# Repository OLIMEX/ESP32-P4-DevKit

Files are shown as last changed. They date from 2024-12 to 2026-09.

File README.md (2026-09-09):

# ESP32-P4-DevKit
Development board for ESP32-P4 Dual core RISCV processor from Espressif

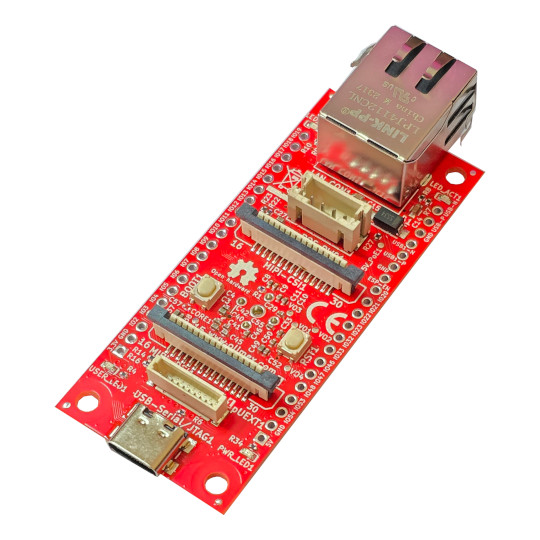
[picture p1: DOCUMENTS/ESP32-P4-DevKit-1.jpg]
ESP32-P4-DevKit-1


https://www.olimex.com/Products/IoT/ESP32-P4/ESP32-P4-DevKit/open-source-hardware

## MIPI-LCD2.8 demos

The ESP-IDF MIPI display demos under `SOFTWARE/Demo_Examples` support both Olimex MIPI-LCD2.8 revisions. They default to WLK2802MIPI-15P-V2. See the per-demo readmes for build instructions and [CHANGELOG.md](CHANGELOG.md) for this revision's configuration changes.

## Licensee
* Hardware is released under CERN Open Hardware Licence Version 2 - Strongly Reciprocal
* Software is released under GPL V3 Licensee
* Documentation is released under CC BY-SA 4.0

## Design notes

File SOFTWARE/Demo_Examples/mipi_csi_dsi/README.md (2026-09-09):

| Supported ESP SoCs | ESP32-P4 |
| --- | ----- |

# MIPI camera and display demo

## Overview

This example streams camera input to the display. It requires a camera, display,
and ESP32-P4 board. It supports both MIPI-LCD2.8 revisions.

## How to use

### ESP-IDF Required

* This demo was made and tested with ESP-IDF `v5.4.1`.
* Please follow the [ESP-IDF Programming Guide](https://docs.espressif.com/projects/esp-idf/en/latest/esp32s3/get-started/index.html) to set up the development environment.

### Hardware Required

* Main board - Olimex [ESP32-P4-DevKit](https://www.olimex.com/Products/IoT/ESP32-P4/ESP32-P4-DevKit/open-source-hardware)
* Display - Olimex [MIPI-LCD2.8-640x480](https://www.olimex.com/Products/RaspberryPi/MIPI-LCD2.8-640x480/)
* Camera - Olimex [CAMERA-OV5647-5MPIX](https://www.olimex.com/Products/Components/Camera/CAMERA-OV5647-5MPIX/)
* USB cable - Type C USB 3.0 cable [USB-CABLE-AM-USB3-C](https://www.olimex.com/Products/Components/Cables/USB/USB-CABLE-AM-USB3-C/)

Connect the camera to MIPI-CSI connector and connect the display to MIPI-DSI connector. Power the main board via the USB type C cable.

### Configurations

V2 (`WLK2802MIPI-15P-V2`) is the default. It uses RGB888 with one MIPI DSI
lane at 500 Mbps and a 16 MHz DPI clock; it has no PCA9536 control expander.

For the original V1 (`WLK2802MIPI-15P`), edit
`main/BOARD_OLIMEX_ESP32_P4_DEVKIT.h` and change:

```c
#define OLIMEX_MIPI_LCD_VERSION (2)
```

to:

```c
#define OLIMEX_MIPI_LCD_VERSION (1)
```

V1 uses the PCA9536 at I2C address `0x41` on GPIO7/GPIO8 for the required
panel reset and backlight sequence. The camera-to-display path remains RGB888.

The demo is otherwise already configured. To review its project settings:

- Run `idf.py menuconfig`

  - See [Configuration Guide](../../../docs/envs/use_with_idf.md#configuration-guide) for more details.

### Build and Flash

Run `idf.py -p <PORT> build flash monitor` to build, flash and monitor the project.

(To exit the serial monitor, type `Ctrl-]`.)

See the [Getting Started Guide](https://docs.espressif.com/projects/esp-idf/en/latest/get-started/index.html) for full steps to configure and use ESP-IDF to build projects.

Generated `build/`, `managed_components/`, and `sdkconfig.old` files are local
build output and should not be committed.

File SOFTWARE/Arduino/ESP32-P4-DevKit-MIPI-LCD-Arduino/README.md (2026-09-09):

# ESP32-P4-DevKit MIPI-LCD2.8 Arduino demo

Arduino/LVGL demo for the Olimex ESP32-P4-DevKit or ESP32-P4-PC and the
MIPI-LCD2.8-640x480 V1 (`WLK2802MIPI-15P`) or V2 (`WLK2802MIPI-15P-V2`)
display. It configures the ST7701 panel for one-lane MIPI DSI, renders an LVGL
status screen, and animates the progress bar continuously. The background
switches between six solid colors every 10 seconds, with text and bar colors
adjusted for contrast. GPIO2 drives the board user LED as a 1 Hz heartbeat.

The display path is RGB888. LVGL renders RGB565 and the local port converts
each updated area to RGB888 before it is copied to the MIPI DSI framebuffer.

## Requirements

- Olimex ESP32-P4-DevKit or ESP32-P4-PC, with the display connected to its
  **MIPI-DSI** connector.
- MIPI-LCD2.8-640x480 V1 or V2 display and its ribbon cable.
- Arduino IDE with **esp32 by Espressif Systems 3.3.8** installed through
  Boards Manager.
- These libraries installed through Library Manager:

| Library | Tested version |
| --- | --- |
| ESP32_Display_Panel | 1.0.4 |
| ESP32_IO_Expander | 1.1.1 |
| esp-lib-utils | 0.3.0 |
| lvgl | 8.4.0 |

Use LVGL 8.4.0. The project does not support LVGL 9.

## Arduino IDE settings

Open `ESP32-P4-DevKit-MIPI-LCD-Arduino.ino`, then select:

| Tools setting | Value |
| --- | --- |
| Board | ESP32P4 Dev Module |
| USB Mode | Hardware CDC and JTAG |
| USB CDC On Boot | **Enabled** |
| Upload Mode | UART0 / Hardware CDC |
| Flash Frequency | 80 MHz |
| Flash Mode | DIO |
| Flash Size | 16 MB |
| **PSRAM** | **Enabled — required** |
| Chip Variant | Before v3.00 for ESP32-P4 revision 1.3 |

`PSRAM: Enabled` is mandatory. The RGB888 480x640 MIPI DSI framebuffer needs
921,600 bytes of PSRAM. If PSRAM is disabled, startup stops with:

```text
lcd.dsi: no memory for frame buffer
Board begin failed
```

Use the appropriate chip variant if the board has later silicon.

## Upload and run

1. Power off before fitting or changing the LCD ribbon.
2. Connect the display to MIPI-DSI, power the board, and select its COM port.
3. Verify, then Upload from Arduino IDE.
4. Apply the Windows DTR/RTS override below before opening Serial Monitor.
5. Open Serial Monitor at **115200 baud**. Startup diagnostics and an `alive`
   message every two seconds confirm that the sketch is running.

Expected startup output includes:

```text
Mode 3: LVGL UI
V2 LCD: no PCA9536; RGB565 LVGL converted to RGB888 display data
PSRAM: total=33554432 free=...; internal free=...
LCD frame: 480x640, color bits: 24
Initializing LVGL
Creating UI
LCD initialized
```

## Prevent Serial Monitor resets (DTR/RTS)

On Windows, closing Arduino IDE's Serial Monitor can change the DTR/RTS control
lines and reset this ESP32-P4 board. The problem was not reproduced with the
same board, cable, and LED test on Linux.

Before using Serial Monitor, copy
`arduino-esp32-boards.local.txt` to the installed ESP32 Arduino-core directory
and rename it to `boards.local.txt`. For Arduino core 3.3.8 on Windows, that is:

```text
C:\Users\<your-user>\AppData\Local\Arduino15\packages\esp32\hardware\esp32\3.3.8\boards.local.txt
```

Restart Arduino IDE after copying it. The override makes its monitor default to
`DTR: off` and `RTS: off` for **ESP32P4 Dev Module**. It is retained when IDE
starts again, but must be copied again after updating the ESP32 board package.

Serial diagnostics are enabled by default. To make a silent build, set
`OLIMEX_DEBUG_SERIAL` to `0` near the top of the sketch and upload again.

The screen shows the Olimex title, display status, and a progress bar that
continuously fills and empties.

## Diagnostic modes

The default in the sketch is the animated LVGL interface:

```cpp
#define OLIMEX_LCD_TEST_MODE TEST_MODE_LVGL_UI
```

For link diagnosis, change that one definition to either:

```cpp
#define OLIMEX_LCD_TEST_MODE TEST_MODE_DSI_PATTERN
// or
#define OLIMEX_LCD_TEST_MODE TEST_MODE_SOFTWARE_COLOR_BARS
```

The DSI-pattern mode bypasses LVGL and cycles controller-generated patterns.
Software color bars exercise the framebuffer path without the LVGL UI.

## Select the display revision

The default is V2. In `esp_panel_board_custom_conf.h`, leave this line as `2`:

```cpp
#define OLIMEX_MIPI_LCD_VERSION (2)
```

For the original V1 display, change it to `1`, then compile and upload again:

```cpp
#define OLIMEX_MIPI_LCD_VERSION (1)
```

V1 enables the PCA9536 I2C expander at address `0x41` for the documented reset
sequence and backlight control. V2 leaves that expander disabled because it is
not populated. Both revisions use the same ST7701 MIPI-DSI RGB888 display path.
Both selections compile with the listed Arduino dependencies; V2 was verified
on the connected display.

## Notes and limitations

- Touch is not implemented.
- The display uses one DSI lane at 500 Mbps and a 16 MHz DPI clock, as used by
  the working V2 test.

## User LED heartbeat

GPIO2 drives the user LED with a 500 ms on / 500 ms off heartbeat. This is
available on both the ESP32-P4-DevKit and ESP32-P4-PC, and gives a quick
indication that the sketch is still running even when Serial Monitor is closed.

The sketch assumes an active-high LED. If a board revision uses an active-low
LED, set this near the top of the `.ino` file before compiling:

```cpp
#define OLIMEX_USER_LED_ACTIVE_LEVEL LOW
```

## Project files

- `arduino-esp32-boards.local.txt` - Windows Serial Monitor DTR/RTS override.
- `ESP32-P4-DevKit-MIPI-LCD-Arduino.ino` — application and animated UI.
- `esp_panel_board_custom_conf.h` — V1/V2 selection, ST7701 init sequence,
  MIPI DSI timing, and the V1 expander setup.
- `esp_panel_drivers_conf.h` — enabled ESP32_Display_Panel drivers.
- `lvgl_v8_port.cpp` / `lvgl_v8_port.h` — LVGL display port and RGB565-to-RGB888
  conversion.
- `lv_conf.h` — project-local LVGL 8 configuration.

Do not commit generated `build*` directories, `.elf`, `.bin`, `.o`, or Arduino
IDE temporary files. See the repository `.gitignore` for the generated-output
patterns.

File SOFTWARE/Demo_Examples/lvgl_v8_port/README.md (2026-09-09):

| Supported ESP SoCs | ESP32 | ESP32-C3 | ESP32-C6 | ESP32-H2 | ESP32-S2 | ESP32-S3 | ESP32-P4 |
| --- | ----- | --- | --- | --- | --- | --- | --- |

# LVGL (v8) Porting Example

## Overview

This example demonstrates how to port `LVGL v8`. And it runs LVGL's internal demos include `Music Player`, `Widgets`, `Stress` and `Benchmark`.

This example also shows three methods to avoid tearing effect when using `RGB/MIPI-DSI` interface LCD. It uses two or more frame buffers based on LVGL **buffering modes**. For more information about this, please refer to [LVGL documents](https://docs.lvgl.io/8.4/porting/display.html?highlight=buffering%20mode#buffering-modes).

## How to use

### ESP-IDF Required

* This demo was made and tested with ESP-IDF `v5.4.1`.
* Please follow the [ESP-IDF Programming Guide](https://docs.espressif.com/projects/esp-idf/en/latest/esp32s3/get-started/index.html) to set up the development environment.

### Hardware Required

* Olimex [ESP32-P4-DevKit](https://www.olimex.com/Products/IoT/ESP32-P4/ESP32-P4-DevKit/open-source-hardware)
* Display - Olimex [MIPI-LCD2.8-640x480](https://www.olimex.com/Products/RaspberryPi/MIPI-LCD2.8-640x480/)
* USB cable

### Configurations

The demo defaults to the current **WLK2802MIPI-15P-V2** LCD. It sends RGB888 over one DSI lane at 500 Mbps with a 16 MHz DPI clock; it does not use a PCA9536 expander. LVGL remains RGB565 internally and converts each flushed region to RGB888 before it reaches the LCD frame buffer.

For the original **WLK2802MIPI-15P** LCD, set `OLIMEX_MIPI_LCD_VERSION` to `1` near the top of `main/BOARD_OLIMEX_ESP32_P4_DEVKIT.h`. V1 uses RGB565, a 1000 Mbps DSI lane, a 25 MHz DPI clock, and a direct PCA9536 reset/backlight sequence at I2C address `0x41` (SDA GPIO7, SCL GPIO8). The project remains self-contained.

The demo is already configured, but if you wish you can check the menuconfig settings the following way:

- Run `idf.py menuconfig`
- Go to `Example Configurations`:

  - `Avoid Tearing Mode`: Select the avoid tearing mode you want to use. Only valid for `RGB/MIPI-DSI` interface LCDs.
  - `Rotation Degree`: Select the rotation degree you want to use. Only valid when `Avoid Tearing Mode` is not `None`.

- Go to `ESP Display Panel Configurations`:

  - See [Configuration Guide](../../../docs/envs/use_with_idf.md#configuration-guide) for more details.

### Build and Flash

Run `idf.py -p <PORT> build flash monitor` to build, flash and monitor the project.

`build/` and `managed_components/` are generated locally. They are intentionally ignored by Git and are not part of the upload.

(To exit the serial monitor, type `Ctrl-]`.)

See the [Getting Started Guide](https://docs.espressif.com/projects/esp-idf/en/latest/get-started/index.html) for full steps to configure and use ESP-IDF to build projects.

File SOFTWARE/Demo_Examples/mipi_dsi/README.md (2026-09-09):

| Supported Targets | ESP32-P4 |
| --- | --- |

# MIPI DSI LCD Panel Example

This demo is based on [esp_lcd](https://docs.espressif.com/projects/esp-idf/en/latest/esp32p4/api-reference/peripherals/lcd/dsi_lcd.html) and modified for Olimex ESP32-P4-DevKit. This project supports MIPI DSI interfaced LCD panel, with frame buffer(s) managed by the driver itself.

This example shows the general process of installing a MIPI DSI LCD driver, and displays a LVGL widget on the screen.

This demo was made and tested with ESP-IDF `v5.4.1`.

## How to use the example

### Hardware Required

* Olimex ESP32-P4-DevKit development board, which with MIPI DSI peripheral supported
* A general MIPI DSI LCD panel, with 1 data lanes and 1 clock lane, this example support [ST7701S](https://www.olimex.com/Products/RaspberryPi/MIPI-LCD2.8-640x480/).
* An USB cable for power supply and programming

### Hardware Connection

The connection between ESP Board and the LCD is simple, just use the flat ribbon cable (included in the display package).

Pinout as follows:

```text
       ESP Board                         MIPI DSI LCD Panel
+-----------------------+              +-------------------+
|                   GND +--------------+ GND               |
|                       |              |                   |
|                   3V3 +--------------+ VCC               |
|                       |              |                   |
|             DSI_CLK_P +--------------+ DSI_CLK_P         |
|             DSI_CLK_N +              + DSI_CLK_N         |
|                       |              |                   |
|            DSI_DAT0_P +--------------+ DSI_DAT0_P        |
|            DAI_DAT0_N +              + DAI_DAT0_N        |
|                       |              |                   |
|            DSI_DAT1_P +--------------+ DSI_DAT1_P        |
|            DSI_DAT1_N +              + DSI_DAT1_N        |
|                       |              |                   |
|                       |              |                   |
|              BK_LIGHT +--------------+ BLK               |
|                       |              |                   |
|                 Reset +--------------+ Reset             |
|                       |              |                   |
+-----------------------+              +-------------------+
```

### Configure

The project defaults to the current **WLK2802MIPI-15P-V2** LCD: RGB888 display data, one DSI lane at 500 Mbps, a 16 MHz DPI clock, and no PCA9536 I2C expander.

To build for the original **WLK2802MIPI-15P** LCD, change `OLIMEX_MIPI_LCD_VERSION` near the top of `main/mipi_dsi_lcd_example_main.c` from `2` to `1`. V1 enables the PCA9536 at I2C address `0x41` for reset/backlight and uses RGB565 display data, 1000 Mbps, and a 25 MHz DPI clock. The supplied `sdkconfig.defaults` is V2/24-bit. For a clean V1 configuration run `idf.py -D SDKCONFIG_DEFAULTS="sdkconfig.defaults;sdkconfig.defaults.v1" reconfigure`, then build and flash.

Run `idf.py menuconfig` and go to `Example Configuration`:

* Choose the LCD model in `Select MIPI LCD model` according to your board.
* Choose whether to `Use DMA2D to copy draw buffer to frame buffer` asynchronously. If you choose `No`, the draw buffer will be copied to the frame buffer synchronously by CPU.
* Choose if you want to `Monitor Refresh Rate by GPIO`. If you choose `Yes`, then you can attach an oscilloscope or logic analyzer to the GPIO pin to monitor the Refresh Rate of the display.
  Please note, the actual Refresh Rate should be **double** the square wave frequency.

### Build and Flash

Run `idf.py -p PORT build flash monitor` to build, flash and monitor the project. A LVGL widget should show up on the LCD as expected.

`build/` and `managed_components/` are generated locally. They are intentionally ignored by Git and are not part of the upload.

The first time you run `idf.py` for the example will cost extra time as the build system needs to address the component dependencies and downloads the missing components from the ESP Component Registry into `managed_components` folder.

(To exit the serial monitor, type ``Ctrl-]``.)

See the [Getting Started Guide](https://docs.espressif.com/projects/esp-idf/en/latest/get-started/index.html) for full steps to configure and use ESP-IDF to build projects.

### Example Output

```bash
...
I (1629) example: MIPI DSI PHY Powered on
I (1629) example: Install MIPI DSI LCD control panel
I (1639) ili9881c: ID1: 0x98, ID2: 0x81, ID3: 0x5c
I (1779) example: Install MIPI DSI LCD data panel
I (1799) example: Initialize LVGL library
I (1799) example: Allocate separate LVGL draw buffers from PSRAM
I (1809) example: Use esp_timer as LVGL tick timer
I (1809) example: Create LVGL task
I (1809) example: Starting LVGL task
I (1919) example: Display LVGL Meter Widget
...
```

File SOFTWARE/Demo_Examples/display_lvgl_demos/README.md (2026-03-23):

# BSP: Display LVGL Demos

## Overview

<table>
<tr><td valign="top">

This example shows LVGL internal demo - LVGL demo player (all LVGL examples are included).

This demo is tested and confirmed working with Olimex ESP32-P4-DevKit and Olimex MIPI-HDMI!

Remembery that you also need a cable FPC-15-1.0-150 between the two boards.

</td><td width="200" valign="top">
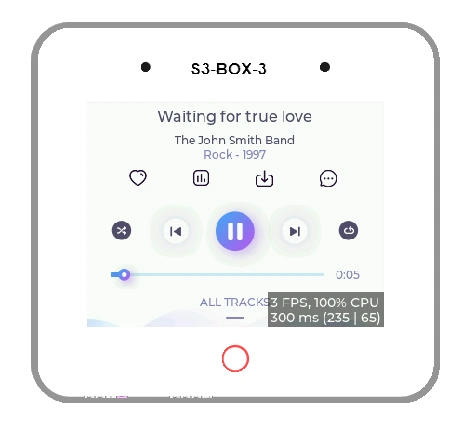
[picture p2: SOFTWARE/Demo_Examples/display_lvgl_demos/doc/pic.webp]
  
</td></tr>
</table>

## Build and Flash

To build and flash the example for a specific `{board}` and `{port}`, use the following command:

```
idf.py -D SDKCONFIG_DEFAULTS=sdkconfig.bsp.{board} -p {port} flash monitor
```
Make sure the correct board name is set in the `main/idf_component.yml` file under the `dependencies` section.

### Example outputs

```
...
I (0) cpu_start: App cpu up.
I (923) esp_psram: SPI SRAM memory test OK
I (932) cpu_start: Pro cpu start user code
I (932) cpu_start: cpu freq: 240000000 Hz
I (932) cpu_start: Application information:
I (935) cpu_start: Project name:     display_lvgl_demos
I (941) cpu_start: App version:      squareline-latest-29-geed37e1
I (948) cpu_start: Compile time:     Dec  2 2023 15:41:34
I (954) cpu_start: ELF file SHA256:  fb3ec2c6026f1bb4...
I (960) cpu_start: ESP-IDF:          v5.1.2
I (965) cpu_start: Min chip rev:     v0.0
I (969) cpu_start: Max chip rev:     v0.99
I (974) cpu_start: Chip rev:         v0.2
I (979) heap_init: Initializing. RAM available for dynamic allocation:
I (986) heap_init: At 3FC9BF28 len 0004D7E8 (309 KiB): DRAM
I (992) heap_init: At 3FCE9710 len 00005724 (21 KiB): STACK/DRAM
I (999) heap_init: At 3FCF0000 len 00008000 (32 KiB): DRAM
I (1005) heap_init: At 600FE010 len 00001FD8 (7 KiB): RTCRAM
I (1011) esp_psram: Adding pool of 15552K of PSRAM memory to heap allocator
I (1019) spi_flash: detected chip: gd
I (1023) spi_flash: flash io: qio
W (1027) spi_flash: Detected size(16384k) larger than the size in the binary image header(2048k). Using the size in the binary image header.
I (1041) sleep: Configure to isolate all GPIO pins in sleep state
I (1048) sleep: Enable automatic switching of GPIO sleep configuration
I (1055) app_start: Starting scheduler on CPU0
I (1060) app_start: Starting scheduler on CPU1
I (1060) main_task: Started on CPU0
I (1070) esp_psram: Reserving pool of 32K of internal memory for DMA/internal allocations
I (1078) main_task: Calling app_main()
I (1083) bsp_probe: Detect module with 16MB PSRAM
I (1088) bsp_probe: Detect sub_board3 with 800x480 LCD (ST7262), Touch (GT1151)
I (1096) bsp_sub_board: Initialize RGB panel
I (1134) gt1151: IC version: GT1158_000101(Patch)_0102(Mask)_00(SensorID)
I (1136) bsp_lvgl_port: Create LVGL task
I (1136) bsp_lvgl_port: Starting LVGL task
I (1164) app_main: Avoid lcd tearing effect
I (1165) app_main: LVGL direct-mode
W (1165) S3-LCD-EV-BOARD: This board doesn't support to change brightness of LCD
I (1171) app_main: Display LVGL demo
I (1370) main_task: Returned from app_main()
```

## Launch Example

You can also try this example using ESP Launchpad:

<a href="https://espressif.github.io/esp-launchpad/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">
    Try it with ESP Launchpad
</a>

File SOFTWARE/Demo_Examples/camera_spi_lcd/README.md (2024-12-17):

| Supported Targets | ESP32-P4 |
| --- | --- |

# Camera display via SPI example

## Overview

This example demonstrates how to use the esp_driver_cam component to capture camera sensor signals and display it via SPI interface. This example will auto-detect camera sensors via [ESP camera sensor driver](https://components.espressif.com/components/espressif/esp_cam_sensor/versions/0.5.3) and capture camera sensor signals via CSI interface and display it via SPI interface.

## Usage

Example was made with ESP-IDF version 5.4.0.

You can have more than one version of ESP-IDF.

ESP-IDF Extension for VS Code Installation
https://github.com/espressif/vscode-esp-idf-extension/blob/master/README.md

The subsections below give only absolutely necessary information. For full steps to configure ESP-IDF and use it to build and run projects, see [ESP-IDF Getting Started](https://docs.espressif.com/projects/esp-idf/en/latest/get-started/index.html#get-started).

### Hardware Required

- Olimex ESP32-P4-DevKit
- MOD-LCD2.8RTP display
- OV5647 or SC2336 camera sensor, or other camera sensors
- Adapter for the UEXT connectors - UEXT-MPQ or UEXT-PQ
- Cables for the adapter and the boards to connect everything

**Note:** OV5647 has its own ISP functions, whereas SC2336 is a camera sensor without ISP functions. You can use the ESP on-chip ISP functions to tune the image together with the sensor ISP functions, if the image quality is not as expected.

You can also connect camera sensors and LCD screens from other vendors to the ESP chip, you can find corresponding camera or LCD drivers from [ESP Component Registry](https://components.espressif.com), or design your own customized drivers.

                                   GND                                           GND
                ┌──────────────────────────────────────┐             ┌────────────────────────────────┐
                │                                      │             │                                │
                │                                      │             │                                │
                │                                ┌─────┴─────────────┴────┐                           │
                │                                │                        │                   ┌───────┴───────┐
                │                                │                        │      SPI MOSI     │               │
                │                                │                        ├───────────────────┤               │
    ┌───────────┴─────────┐ CSI DATA 1P          │                        │                   │               │
    │                     ├──────────────────────┤                        │      SPI CLK      │               │
    │                     │                      │                        ├───────────────────┤               │
    │                     │ CSI DATA 1N          │        ESP32-P4        │                   │   LCD Screen  │
    │       Camera        ├──────────────────────┤                        │      SPI CS       │               │
    │                     │                      │                        ├───────────────────┤               │
    │                     │ CSI CLK N            │                        │                   │               │
    │                     ├──────────────────────┤                        │      LCD DC       │               │
    │                     │                      │                        ├───────────────────┤               │
    │                     │ CSI CLK P            │                        │                   └───────────────┘
    │                     ├──────────────────────┤                        │
    │                     │                      │                        |
    │                     │ CSI DATA 0P          │                        │
    │                     ├──────────────────────┤                        │
    │                     │                      │                        |
    │                     │ CSI DATA 0N          │                        │
    │                     ├──────────────────────┤                        │                           
    └───────┬──┬──────────┘                      │                        │
            │  │           I2C SCL               │                        │
            │  └─────────────────────────────────┤                        │
            │              I2C SDA               │                        │
            └────────────────────────────────────┤                        │
                                                 └────────────────────────┘

### Set Chip Target

First of all, your target must be supported by both:

- **By your ESP-IDF version**: For the full list of supported targets, run:
  ```
  idf.py --list-targets
  ```
- **By this example**: For the full list of supported targets,  refer to the supported targets table at the top of this README.

After you make sure that your target is supported, go to your example project directory and [set the chip target](https://docs.espressif.com/projects/esp-idf/en/latest/api-guides/tools/idf-py.html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):

```
idf.py set-target <target>
```

For example, to set esp32-P4 as the chip target, run:

```
idf.py set-target esp32p4
```

### Configure the Project

For information about Kconfig options, see [Project Configuration](https://docs.espressif.com/projects/esp-idf/en/latest/api-reference/kconfig.html) > _Name of relevant section(s)_.

To conveniently check or modify Kconfig options for this example in a project configuration menu, run:

```
idf.py menuconfig
```

```
Set CONFIG_CAMERA_OV5647 to y
Set CONFIG_CAMERA_SC2336 to y
```

### Build and Flash

Execute the following command to build the project, flash it to your development board, and run the monitor tool to view the serial output:

```
idf.py build flash monitor
```

This command can be reduced to `idf.py flash monitor`.

If the above command fails, check the log on the serial monitor which usually provides information on the possible cause of the issue.

To exit the serial monitor, use `Ctrl` + `]`.

## Example Output

If you see the following console output, your example should be running correctly:

```
I (1085) main_task: Calling app_main()
I (1095) ili9881c: ID1: 0x98, ID2: 0x81, ID3: 0x5c
I (1125) gpio: GPIO[31]| InputEn: 1| OutputEn: 1| OpenDrain: 1| Pullup: 1| Pulldown: 0| Intr:0
I (1125) gpio: GPIO[34]| InputEn: 1| OutputEn: 1| OpenDrain: 1| Pullup: 1| Pulldown: 0| Intr:0
I (1295) ov5647: Detected Camera sensor PID=0x5647 with index 0
I (1305) cam_dsi: fmt[0].name:MIPI_2lane_24Minput_RAW8_800x1280_50fps
I (1305) cam_dsi: fmt[1].name:MIPI_2lane_24Minput_RAW8_800x640_50fps
I (1315) cam_dsi: fmt[2].name:MIPI_2lane_24Minput_RAW8_800x800_50fps
I (1355) cam_dsi: Format in use:MIPI_2lane_24Minput_RAW8_800x640_50fps
```

## Reference

- Link to the ESP-IDF feature's API reference, for example [ESP-IDF: Camera Controller Driver](https://docs.espressif.com/projects/esp-idf/en/latest/api-reference/peripherals/camera_driver.html)
- [ESP-IDF Getting Started](https://docs.espressif.com/projects/esp-idf/en/latest/get-started/index.html#get-started)
- [Project Configuration](https://docs.espressif.com/projects/esp-idf/en/latest/api-reference/kconfig.html) (Kconfig Options)

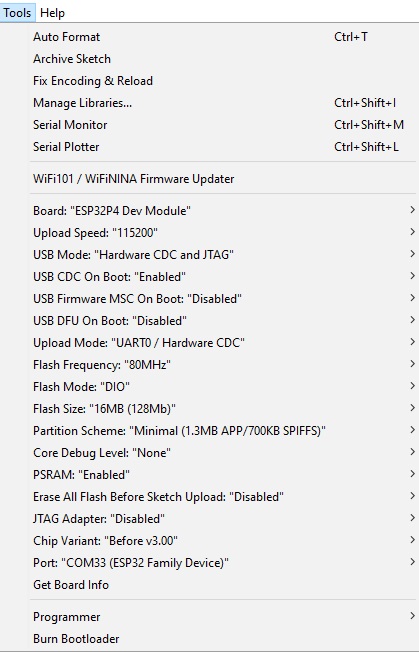
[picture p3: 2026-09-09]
SOFTWARE/Arduino/ESP32-P4-blink-serial-demo/ESP32-P4-settings-arduino.jpg

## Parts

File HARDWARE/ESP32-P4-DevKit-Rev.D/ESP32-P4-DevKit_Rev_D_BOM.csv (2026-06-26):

Quantity | Value | Footprint | Reference
2 | YTS-A016-X | YTS-A016-X | BOOT1, RST1
4 | 22pF/50V/5%/C0G/C0402 | C_0402_5MIL_DWS | C1, C2, C43, C44
9 | 10uF/6.3V/20%/X5R/C0402 | C_0402_5MIL_DWS | C3, C6, C18, C20, C22, C27, C37, C40, C49
23 | 100nF/10V/20%/X5R/C0402 | C_0402_5MIL_DWS | C4, C5, C7, C9, C11, C12, C19, C21, C23, C28, C29, C35, C38, C39, C41, C42, C45, C46, C48, C50, C51, C52, C53
8 | 1uF/6.3V/10%/X5R/C0402 | C_0402_5MIL_DWS | C8, C10, C33, C36, C47, C54, C55, C58
1 | 4.7uF/X5R/20%/10V/C0402 | C_0402_5MIL_DWS | C13
2 | 100nF/50V/20%/Y5V/C0603 | C_0603_5MIL_DWS | C14, C15
1 | 1nF/2000V/10%/X7R/C1206 | C_1206_5MIL_DWS_ISO | C16
2 | 47uF/6.3V/20%/X5R/C0805 | C_0805_5MIL_DWS | C17, C62
2 | 27pF/50V/5%/C0G/C0402 | C_0402_5MIL_DWS | C24, C25
3 | 22uF/6.3V/20%/X5R/C0603 | C_0603_5MIL_DWS | C32, C34, C60
2 | 150pF/50V/2%/NP0/C0402 | C_0402_5MIL_DWS | C63, C64
1 | 1N5822/SS34/SMA | SMA-KA | D1
2 | WPM2015-3/TR | SOT23 | FET1, FET2
2 | 600OHM/2A/UPZ2012E-601-2R0TF/0805 | L_0805_5MIL_DWS | L1, L2
2 | 1.0uH/4.2A/DCR=35mR/20%/2.00x1.60x1.00mm/L2016(PIM201610-1R0MTS00) | L_2016_MM | L3, L4
1 | RJP-003TC1(LPJ4112CNL) | RJP-003TC1(LPJ4112CNL) | LAN_CON1
1 | LED/Yellow/0603 | LED_0603_KA | LED_ACT1
2 | LED/Green/0603 | LED_0603_KA | LED_LINK1, USER_LED1
1 | TFC-9P-1.7H(ATFFS150A01BR016) | uSD(TFC-9P-1.xH(ATFFS150A01BR016)) | MICRO_SD1
2 | FPA-VZA2-15-LF | TE_1-1734248-5 | MIPI-CSI1, MIPI-DSI1
1 | PH2.0-4AT | PH2.0-4PLB | POE_PWR1
1 | LED/RED/0603 | LED_0603_KA | PWR_LED1
1 | Q32.768kHz/12.5pF/2P/SMD1206 | CM7V-T1A(Crystal_Package-1206_3.20x1.50x0.65mm) | Q1
1 | Q25MHz/18pF/30ppm/4P/3.2x2.5mm(ABM8-25.000MHZ-D2Y-T) | TSX-3.2x2.5mm_GND(3) | Q2
1 | Q40.000MHz/12pF/10ppm/4P/3.2x2.5x0.70mm(Harmony_Electronics_CORP./HSX321S) | TSX-3.2x2.5mm_GND(3) | Q3
2 | 4.02k/1%/R0402 | R_0402_5MIL_DWS | R1, R2
8 | 4.7k/R0402 | R_0402_5MIL_DWS | R3, R7, R10, R13, R14, R24, R25, R32
6 | 2.2k/R0402 | R_0402_5MIL_DWS | R4, R8, R9, R22, R23, R34
2 | 5.1k/1%/R0402 | R_0402_5MIL_DWS | R5, R6
7 | 10k/R0402 | R_0402_5MIL_DWS | R11, R20, R27, R36, R37, R38, R43
1 | 10M/R0402 | R_0402_5MIL_DWS | R12
1 | 6.19k/1%/R0402 | R_0402_5MIL_DWS | R15
4 | 22R/R0402 | R_0402_5MIL_DWS | R16, R33, R44, R45
2 | 1.5k/R0402 | R_0402_5MIL_DWS | R29, R30
1 | 30.1k/1%/R0402 | R_0402_5MIL_DWS | R39
1 | 6.49k/1%/R0402 | R_0402_5MIL_DWS | R40
2 | 10.5k/1%/R0402 | R_0402_5MIL_DWS | R41, R42
1 | RMAT_(4x0402)_4.7k | RA0805_(4X0402)_xx_BIGGEROUTPADS | RM1
1 | ESDS314DBVR(SOT-23-5) | SOT-23-5 | TVS1
1 | ESP32-P4NRWxx(QFN104) | QFN104_10mm×10mm_Pitch_0.35mm | U1
1 | IP101GRR(32-PIN_QFN) | QFN32_EP(33)_4.00x4.00x0.80mm_Pitch_0.40mm | U2
1 | W25Q128JVSIQ(16MB) | SO-8_208mil | U3
2 | TPS62A02ADRLR(SOT-563-6) | SOT-563-6 | U4, U5
1 | USB-C-16P-F(A40-00119-A52-12) | USB2.0_TYPE-C(A40-00119-A52-12)_Paste | USB-Serial/JTAG1
1 | SH1.0-10P-180D | BM10B-SRSS-TB | pUEXT1

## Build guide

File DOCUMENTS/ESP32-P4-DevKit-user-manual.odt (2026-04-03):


ESP32-P4-DevKit

User Manual

Document revision 2.1, April 2026 | www.olimex.com

# What is ESP32-P4-DevKit

ESP32-P4-DevKit is a development board with ESP32-P4 Dual Core RISC-V processor from Espressif.

The features of ESP32-P4-DevKit board are:

- Espressif ESP32-P4NRW32 module:
  - Dual core 400Mhz RISC-V
  - 768KB RAM
  - 32MB PSRAM
- SPI flash memory 16MB
- USB type C connector for powering, programming, and debugging
- Ethernet PHY (TI TLK110) and connector with POE option via extension
- Camera CSI interface with connector
- Display DSI interface with connector
- MicroSD card
- Boot and Reset buttons
- pUEXT connector
- All GPIOs available on two 0.1″ 2.54 mm 20 pin DIL headers
- Four mounting holes 3.3mm diameter
- Dimensions: (72 x 30)mm

ESP32-P4-DevK is an Open Source design, all design CAD files and firmware are available for download even without a purchase, so people are free to use, study, and modify the design.

## Order codes for ESP32-P4-DevKit and accessories:

ESP32-P4-DevKit (https://www.olimex.com/Products/IoT/ESP32-P4/ESP32-P4-DevKit/) ESP32-P4 development board with Ethernet

UEXT-PQ (https://www.olimex.com/Products/Modules/Adapters/UEXT-PQ/open-source-hardware) pUEXT to UEXT adapter

pUEXT-CABLE (https://www.olimex.com/Products/Modules/Adapters/pUEXT-CABLE-10-10-50MM/) 1mm step pUEXT cable with 50, 100 and 200mm lenght

POEv3 (https://www.olimex.com/Products/IoT/ESP32-P4/POEv3/open-source-hardware) PoE add-on board allowing board to be powered by Ethernet POE

UEXT modules (https://www.olimex.com/Products/Modules/) Many UEXT modules which can connect to Neo6502 UEXT connector

USB-CABLE-AM-USB3-C (https://www.olimex.com/Products/Components/Cables/USB-CABLE-AM-USB3-C/) High speed, high current cable for power supply and programming

(https://www.olimex.com/Products/Components/Cables/USB-CABLE-AM-USB3-C/)

# HARDWARE

## ESP32-P4-DevKit layout

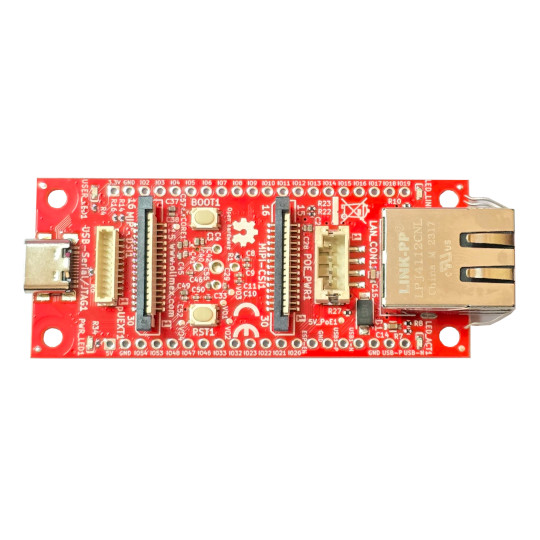
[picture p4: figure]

LED

USB-C JTAG

Power LED

MIPI-DSI

UEXT connector

BOOT button

RESET buttoon

MIPI-CSI

Ethernet

POE

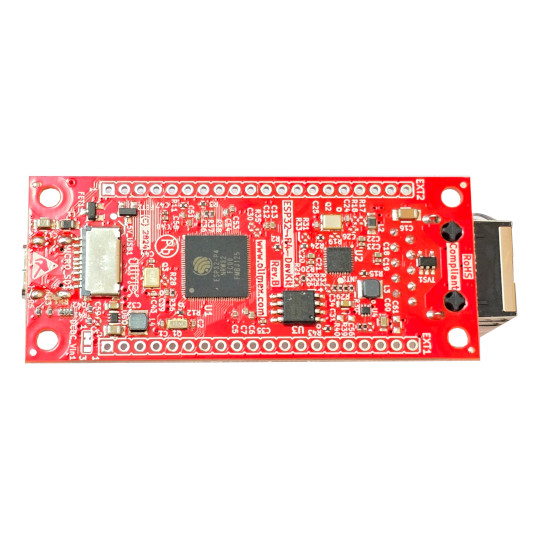
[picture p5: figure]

GPIO connector 2

Micro SD card

GPIO connector 1

SPI flash

## ESP32-P4-DevKit POE connector

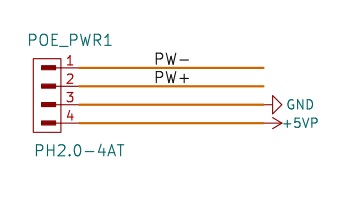
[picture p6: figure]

PW+ and PW- come from the LAN transformer. POEv3 external board have POE negotiator and DCDC step down circuit which produce 5V/3A which is feed back to the ESP32-P4-DevKit.

If you don’t use POE powering, nor POEv3, then header POE_PWR1 can also be used as power input, where pin #4 (+5VP) and pin GND can be used to power the board!

## ESP32-P4-DevKit CSI connector

MIPI-CSI connector follows the standard Raspberry Pi 1, 2, 3, and 4 camera FPC layout. So you can connect standard RPi camera to it.

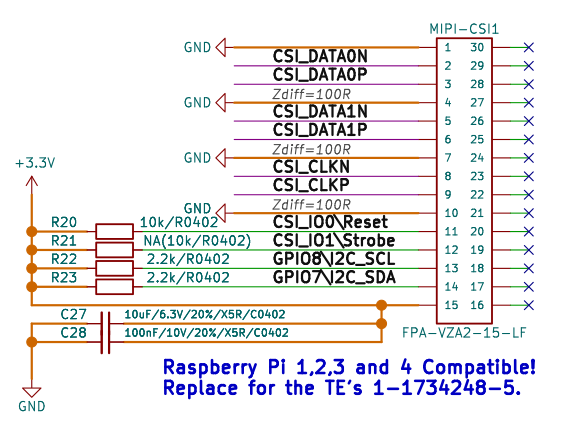
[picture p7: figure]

We have compatible camera here:

https://www.olimex.com/Products/Components/Camera/CAMERA-OV5647-5MPIX/

Demos with the camera are available at the GitHub page of the product.

## ESP32-P4-DevKit MIPI connector

MIPI-DSI is Raspberry Pi DSI connector layout:

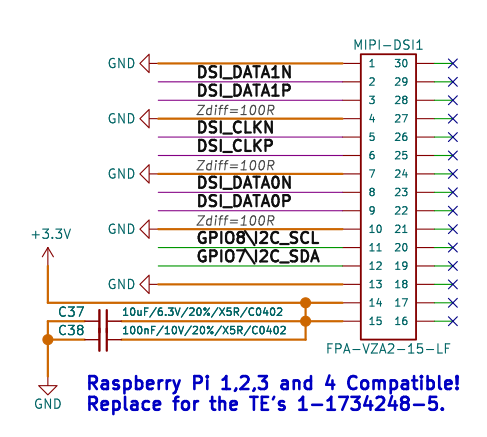
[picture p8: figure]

The ESP32-P4-DevKit board is compatible with Olimex MIPI-HDMI (https://www.olimex.com/Products/IoT/ESP32-P4/MIPI-HDMI/open-source-hardware) adapter. There is also ESP-IDF demo code for the combo:

https://github.com/OLIMEX/ESP32-P4-DevKit/tree/main/SOFTWARE/Demo_Examples/display_lvgl_demos

The ESP32-P4-DevKit board is compatible with Olimex MIPI-LCD2.8-640x480 LCD (https://www.olimex.com/Products/RaspberryPi/MIPI-LCD2.8-640x480/). There is also ESP-IDF demo code for the combo:

https://github.com/OLIMEX/ESP32-P4-DevKit/tree/main/SOFTWARE/Demo_Examples/mipi_dsi

## ESP32-P4-DevKit UEXT connector

ESP32-P4-DevKit is very compact board so standard UEXT connector was impossible to be used, this is why we used pUEXT connector. pUEXT is 1.0 mm step connector but you can use UEXT-PQ (https://www.olimex.com/Products/Modules/Adapters/UEXT-PQ/open-source-hardware) adapter for bigger 2.54mm step. All signals are at 3.3V levels.

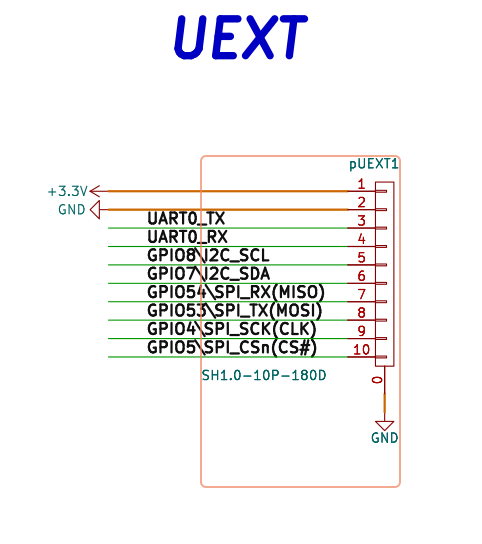
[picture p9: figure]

## ESP32-P4-DevKit EXT1 and EXT2 connectors

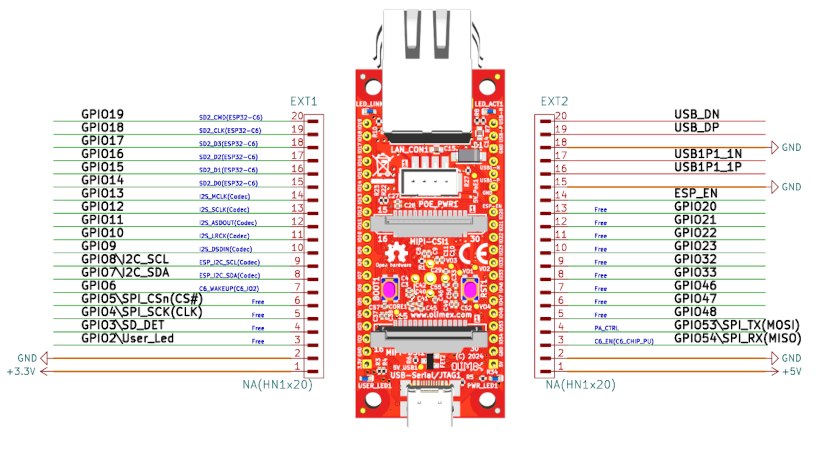
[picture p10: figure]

## ESP32-P4-DevKit schematics

ESP32-P4-DevKit latest design file are available at GitHub (https://github.com/OLIMEX/ESP32-P4-DevKit/tree/main/HARDWARE)

It is open source hardware design made with KiCAD.

# SOFTWARE

ESP32-P4-DevKit can be programmed with ESP-IDF version 5.4 or later.

You can learn how to install it here:

https://docs.espressif.com/projects/esp-idf/en/stable/esp32p4/get-started/index.html

(https://github.com/vsladkov/reload-emulator)

ESP32-P4 is also supported in the official Espressif Arduino IDE package here:

https://github.com/espressif/arduino-esp32

Below is a link to some Arduino demos for ESP32-P4-DevKit:

https://github.com/OLIMEX/ESP32-P4-DevKit/tree/main/SOFTWARE/Arduino

# FAQ

Q: I erased the memory of the board and now it won’t program anymore. I get a notification that the board is disconnected. Did I break the board? Did I receive a broken board?

A: Some boards might experience timeout or perpetual reboot problems after being erased. The workaround is to force higher capacitance via the cable – either use a very long USB cable or if possible extra USB extender cable USB type A male to type A female also connect it to the regular USB type A – type C cable (as sort of USB extension) or maybe connect some USB hubs. The idea of this is to have cabling with higher capacitance between the board and the computer. For more details, refer to this forum thread:

https://www.olimex.com/forum/index.php?topic=9794.0

Q: I can’t seem to find the right settings for this board under Arduino IDE. There are many options. What are the proper settings?

A: Make sure Espressif package is installed and then from Tools → Board use the settings from the picture below:

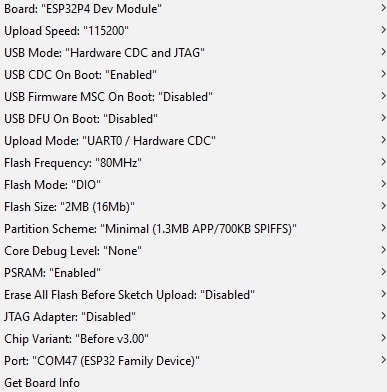
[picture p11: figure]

# Revision History

Revision 2.1 April 2026

- Added FAQ section

Revision 2.0 October 2025

- Removed 2.54mm UEXT connector since it was incorrect.

Revision 1.0 December 2024

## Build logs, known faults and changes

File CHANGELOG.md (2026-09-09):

# Changelog

## MIPI-LCD2.8 V1/V2 revision

### Changed

- `SOFTWARE/Demo_Examples/mipi_dsi` now defaults to the WLK2802MIPI-15P-V2 LCD: RGB888 data, one DSI lane at 500 Mbps, 16 MHz DPI clock, and no PCA9536 access.
- `SOFTWARE/Demo_Examples/lvgl_v8_port` now uses the same V2 defaults and converts its RGB565 LVGL draw data to RGB888 before writing it to the LCD frame buffer.
- Both projects provide the `OLIMEX_MIPI_LCD_VERSION` selector. Set it to `1` for the original WLK2802MIPI-15P display.
- V1 enables the PCA9536 at I2C address `0x41` for the display reset and backlight sequence, and uses RGB565, 1000 Mbps DSI, and a 25 MHz DPI clock.

### Added

- `mipi_dsi/sdkconfig.defaults.v1` supplies the matching LVGL RGB565 default for V1 builds.
- Project readmes explain the two LCD revisions, the default configuration, and the V1 build step.
- Repository `.gitignore` excludes ESP-IDF build output, downloaded `managed_components`, and generated `sdkconfig.old` backups.

### Compatibility

- V2 is the default configuration and is the configuration validated with the current MIPI-LCD2.8 display.
- V1 remains available for original displays with the PCA9536 controller.

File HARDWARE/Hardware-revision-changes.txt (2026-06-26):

Hardware design made with KiCAD. Major board revision (e.g. A, B, C) is printed with white print on the board itself.

Minor revisions (e.g. C1, C2, C3) are revisions that use the same PCB as major board revision but different components. Minor revisions are not printed on the board, but only on the box.

Major changes between board revisions of ESP32-P4-DevKit:

Hardware revision D1
---

Iprovements to the perpetual reboot issue that some boards experience when erased.

1. U5 changed from TPS62A02ADRLR(SOT-563-6) to TLV62585PDRLR(SOT-563-6);
2. C63 and C64 changed from 150pF/50V/2%/NP0/C0402 to NA(150pF/50V/2%/NP0/C0402);

Hardware revision D
---

Improvements to the perpetual reboot issue that some boards experience when erased.

1. R44 and R45, 22R/R0402 added in series to the USB1P1_0P and USB1P1_0N. C63 and C64 (150pF/50V/2%/NP0/C0402) added;
2. L3 and L4 changed from 1.0uH/2.5A/DCR=30mR/20%/3.00x3.00x1.50mm/CD32(SWPA3015S1R0MT) to 1.0uH/4.2A/DCR=35mR/20%/2.00x1.60x1.00mm/L2016(PIM201610-1R0MTS00);
3. Q2's value changed from Q25MHz/20pF/20ppm/4P/3.2x2.5mm to Q25MHz/18pF/30ppm/4P/3.2x2.5mm(ABM8-25.000MHZ-D2Y-T); 
4. C24 and C25 were changed from 33pF/50V/5%/C0G/C0402 to 27pF/50V/5%/C0G/C0402;

Hardware revision C
---

1. The SD card's power supply was corrected as follows:
- FET1's source was disconnected from ESP_LDO_VO4 and connected to +3.3V.
- All RM1 pull-ups and R13 were disconnected from VDD_SD and connected to ESP_LDO_VO4.

2. A lot of improvements for better manfactruing yield in silk and symbols.
3. The revision identifier and the production year were changed.

Hardware revision B
---
Initial release

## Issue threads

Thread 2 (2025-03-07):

GPIO number mismatch for ESP32P4 with IP101 PHY

edwin-oetelaar, 2025-03-07:
https://github.com/OLIMEX/ESP32-P4-DevKit/blob/main/SOFTWARE/Demo_Examples/iperf/sdkconfig.ci.default_ip101

contains numbers which do not match schematic

```
CONFIG_EXAMPLE_ETH_MDC_GPIO=23
CONFIG_EXAMPLE_ETH_MDIO_GPIO=18
CONFIG_EXAMPLE_ETH_PHY_RST_GPIO=5

```
Should be
```

CONFIG_EXAMPLE_ETH_MDC_GPIO=31
CONFIG_EXAMPLE_ETH_MDIO_GPIO=52
CONFIG_EXAMPLE_ETH_PHY_RST_GPIO=51

```
I use the numbers on your board using
```

    eth_esp32_emac_config_t esp32_emac_config = ETH_ESP32_EMAC_DEFAULT_CONFIG();

    esp32_emac_config.smi_gpio.mdc_num = GPIO_NUM_31; // was GPIO_NUM_23;
    esp32_emac_config.smi_gpio.mdio_num = GPIO_NUM_52; // was GPIO_NUM_18;
    esp32_emac_config.interface = EMAC_DATA_INTERFACE_RMII;

    // Create eth MAC
    esp_eth_mac_t *mac = esp_eth_mac_new_esp32(&esp32_emac_config, &mac_config);

    eth_phy_config_t phy_config = ETH_PHY_DEFAULT_CONFIG();
    phy_config.phy_addr = 1;
    phy_config.reset_gpio_num = GPIO_NUM_51; // was GPIO_NUM_5

    esp_eth_phy_t *phy = esp_eth_phy_new_ip101(&phy_config);

```

DanKoloff, 2025-03-10:
I am sorry, but what? What does it mean with IP101? What board does your fix apply to?

This demo is meant for Olimex ESP32-P4-DevKit board and definitions match the schematic. Our board uses LAN8710A.

I attach excerpts below:

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

DanKoloff, 2025-03-10:
I think we set it manually from the menuconfig during testing so yeah.

DanKoloff, 2025-03-10:
Thanks for the report:

https://github.com/OLIMEX/ESP32-P4-DevKit/commit/06068ef919471aae8c1e4e44d692593868d0691f

edwin-oetelaar, 2025-03-10:
https://www.olimex.com/Products/IoT/ESP32-P4/ESP32-P4-DevKit/open-source-hardware

ESP32-P4-DevKit_Rev_B.pdf

DanKoloff, 2025-03-10:
Sorry for the earlier reply I opened wrong schematic and was thinking about another board. My bad.

edwin-oetelaar, 2025-03-10:
No problems, nice products, good thing you built the examples. I support your efforts. Good products, buying your stuff for over a decade... ;-) I am using it for this project : https://www.youtube.com/watch?v=1nkuiaRFE1s using the ESP32 for servo, speed and Remote control. New version will have extra quadrature encoders etc. Hope to write a blog post later. Have a good day.

DanKoloff, 2025-03-10:
Thank you for the kind words, we try our best. Very interesting project and competition. Why did you choose the ESP32-P4 (instead of other ESP32 modules with built-in WIFI/BT)? Do you attach external module for the remote control goal?

edwin-oetelaar, 2025-03-10:
We use a Futaba RC receiver. Left/Right Speed, modes. The ESP32 decodes the pulse width signals, controls servo H bridge with PWM. We have a absolute encoder (using SPI) on the servo. New version will use I2C based encoder. We also have PWM output for creating analog signal (0..5V) for speed. We used the https://www.tinytronics.nl/en/development-boards/microcontroller-boards/with-wi-fi/lilygo-ttgo-t-internet-poe-esp32-lan8720a but we were running out of IO pins, so I chose the ESP32P4 board with many IO pins for the 2025 competition.

Closed 2025-03-10.

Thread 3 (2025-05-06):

How to get serial output in Arduino serial monitor

marekm72, 2025-05-06:
Arduino IDE 2.3.6 with recommended settings https://www.olimex.com/Products/IoT/ESP32-P4/ESP32-P4-DevKit/resources/ESP32-P4-settings-arduino.jpg
I can blink the user LED on GPIO2, but can't see any serial debug output.
I've just found that serial monitor works after I set "USB CDC On Boot: Enabled".
Why is it recommended to disable - are there any downsides to enable it?

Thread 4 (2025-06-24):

Is it possible to build OTG USB on this card ?

DGnice06, 2025-06-24:
Hello,
Is it possible to build OTG USB on this card ?
I see USB1P1_1N and USB1P1_1P , is it correct for OTG ? adding 5V et Ground
Thanks !

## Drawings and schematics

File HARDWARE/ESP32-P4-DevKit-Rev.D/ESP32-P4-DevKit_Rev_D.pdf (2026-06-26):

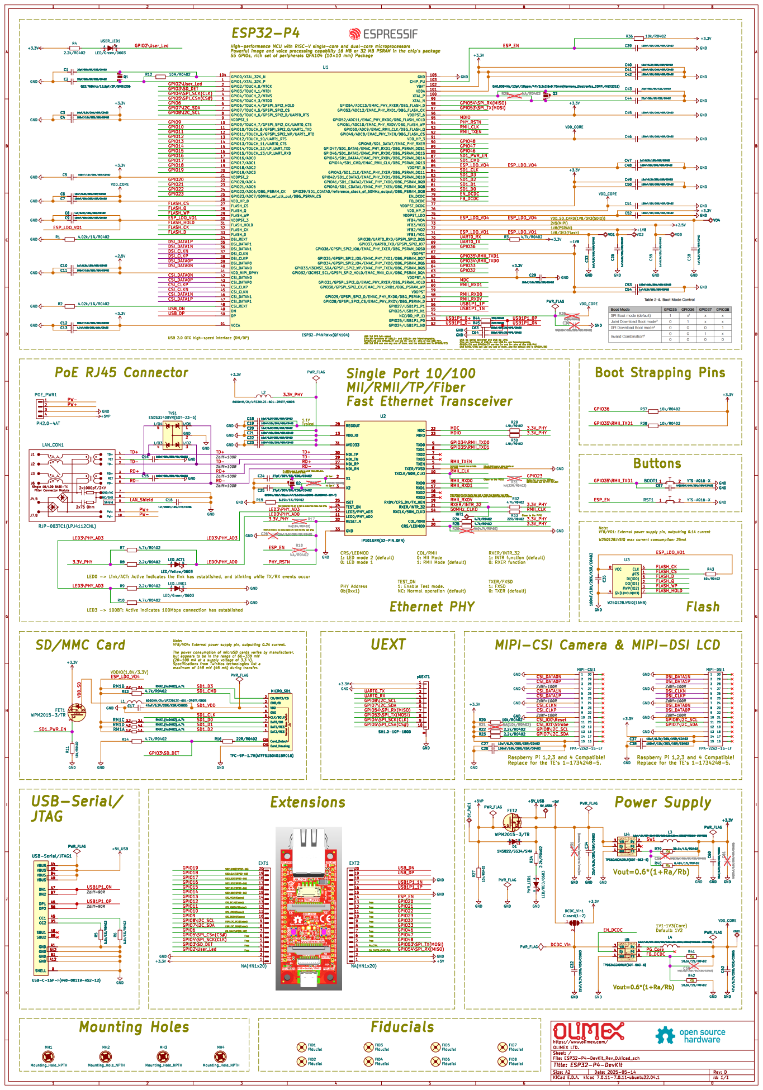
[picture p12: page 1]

+3.3V GND GND GND GND

I2S_SCLK(Codec) Free SD2_CMD(ESP32-C6) SD2_CLK(ESP32-C6) PoE RJ45 Connector

USB 2.0 OTG full-speed

PWR_FLAG
MII/RMII/TP/Fiber
Fast Ethernet Transceiver

50MHz clock out for PHY REF_CLK Fiducials

Option for to use the ESP32's

RESET_N: Enable a low status signal will reset the chip. Type I(PU).

CRS/LEDMOD
1: LED mode 2 (default) 0: LED mode 1

1: Enable Test mode. NC: Normal operation (default) COL/RMII 0: MII Mode

RXER/INTR_32
1: INTR function (default) 0: RXER function

Raspberry Pi 1,2,3 and 4 Compatible! Replace for the TE's 1-1734248-5. PHY Address

9 MIPI-DSI1 FPA-VZA2-15-LF GND GND GND +3.3V

In casea loweroutputrippleisdesired,higheroutputcapacitancecanhelpreducetheripple. Lx=1.0uH
Cout=(10~22)uF/6.3V/X5Rþÿ(Vout"e1.8V). 22uFRecommended! Cout=22uF/6.3V/X5Rþÿ(1.2V"dVout<1.8V) Cout=44uF/6.3V/X5Rþÿ(0.6V"dVout<1.2V) DCR<50mR

Donotfloat. Enablecontrol. FB Input Current,I(FB)=100nA(max) FeedbackReferenceVoltage,V(REF)=0.6V
Rb mustnotbehigherthanþÿ100k© toprovideacceptablenoisesensitivity. ShutdownCurrentI(SHDN)=0.01-2uA
SwitchingFrequency 2.4MHz TPS62A02ADRLR V(ENH)=1.2V

Id: 1/1 Title: ESP32-P4-DevKit File: ESP32-P4-DevKit_Rev_D.kicad_sch Sheet: / OLIMEX LTD. https://www.olimex.com/

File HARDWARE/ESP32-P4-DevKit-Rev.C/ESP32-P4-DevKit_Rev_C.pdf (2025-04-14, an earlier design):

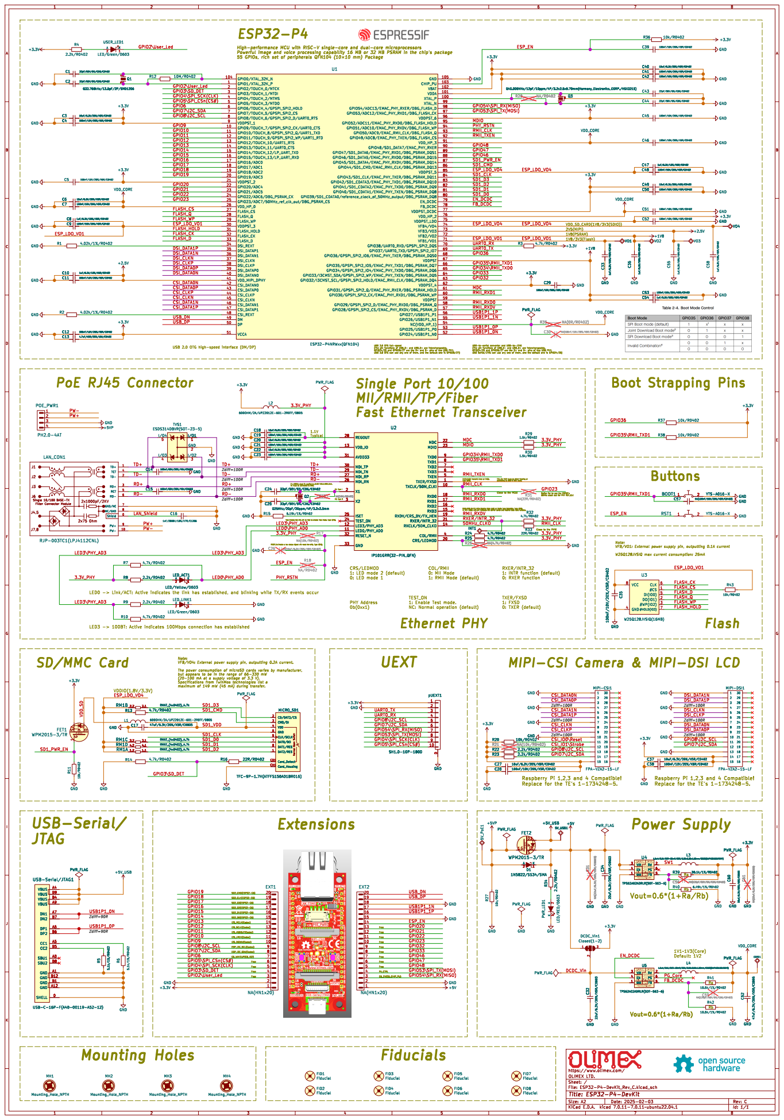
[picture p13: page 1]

USB 2.0 OTG full-speed

MII/RMII/TP/Fiber
Fast Ethernet Transceiver

ESP_LDO_VO1 TD+
RD- Zdiff=100R TD- Zdiff=100R

Option for to use the ESP32's
50MHz clock out for PHY REF_CLK

1: INTR function (default) 0: RXER function COL/RMII 0: MII Mode

1: LED mode 2 (default) 0: LED mode 1 PHY Address

1: Enable Test mode. NC: Normal operation (default)

Vout=0.6*(1+Ra/Rb) Ethernet PHY

RbRa SD/MMC Card

9 MIPI-CSI1 FPA-VZA2-15-LF GND GND GND

3 FET1 WPM2015-3/TR Normal Open Switch DAT2/RES 1 CD/DAT3/CS 2 CMD/DI 3 VDD 4 CLK/SCLK 5 GND 6 DAT0/DO 7 DAT1/RES 8 Card_Detect CD1 Card_Housing CH1 MICRO_SD1 TFC-9P-1.7H(ATFFS150A01BR016) C28 100nF/10V/20%/X5R/C0402

Raspberry Pi 1,2,3 and 4 Compatible! Replace for the TE's 1-1734248-5.

Free Free Free C6_EN(C6_CHIP_PU) PA_CTRL Free Free Free Extensions

2 PWR_LED1 LED/RED/0603 R34 2.2k/R0402(SOT563-6) A 0.47uHinductorcanalsobe usedwiththesamerecommendedoutput capacitorsfortheTPS62A02x. a largervaluereducesinputvoltageripple. Cin=4.7uF/6.3V/X5R

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

Id: 1/1 Title: ESP32-P4-DevKit File: ESP32-P4-DevKit_Rev_C.kicad_sch Sheet: / OLIMEX LTD. https://www.olimex.com/

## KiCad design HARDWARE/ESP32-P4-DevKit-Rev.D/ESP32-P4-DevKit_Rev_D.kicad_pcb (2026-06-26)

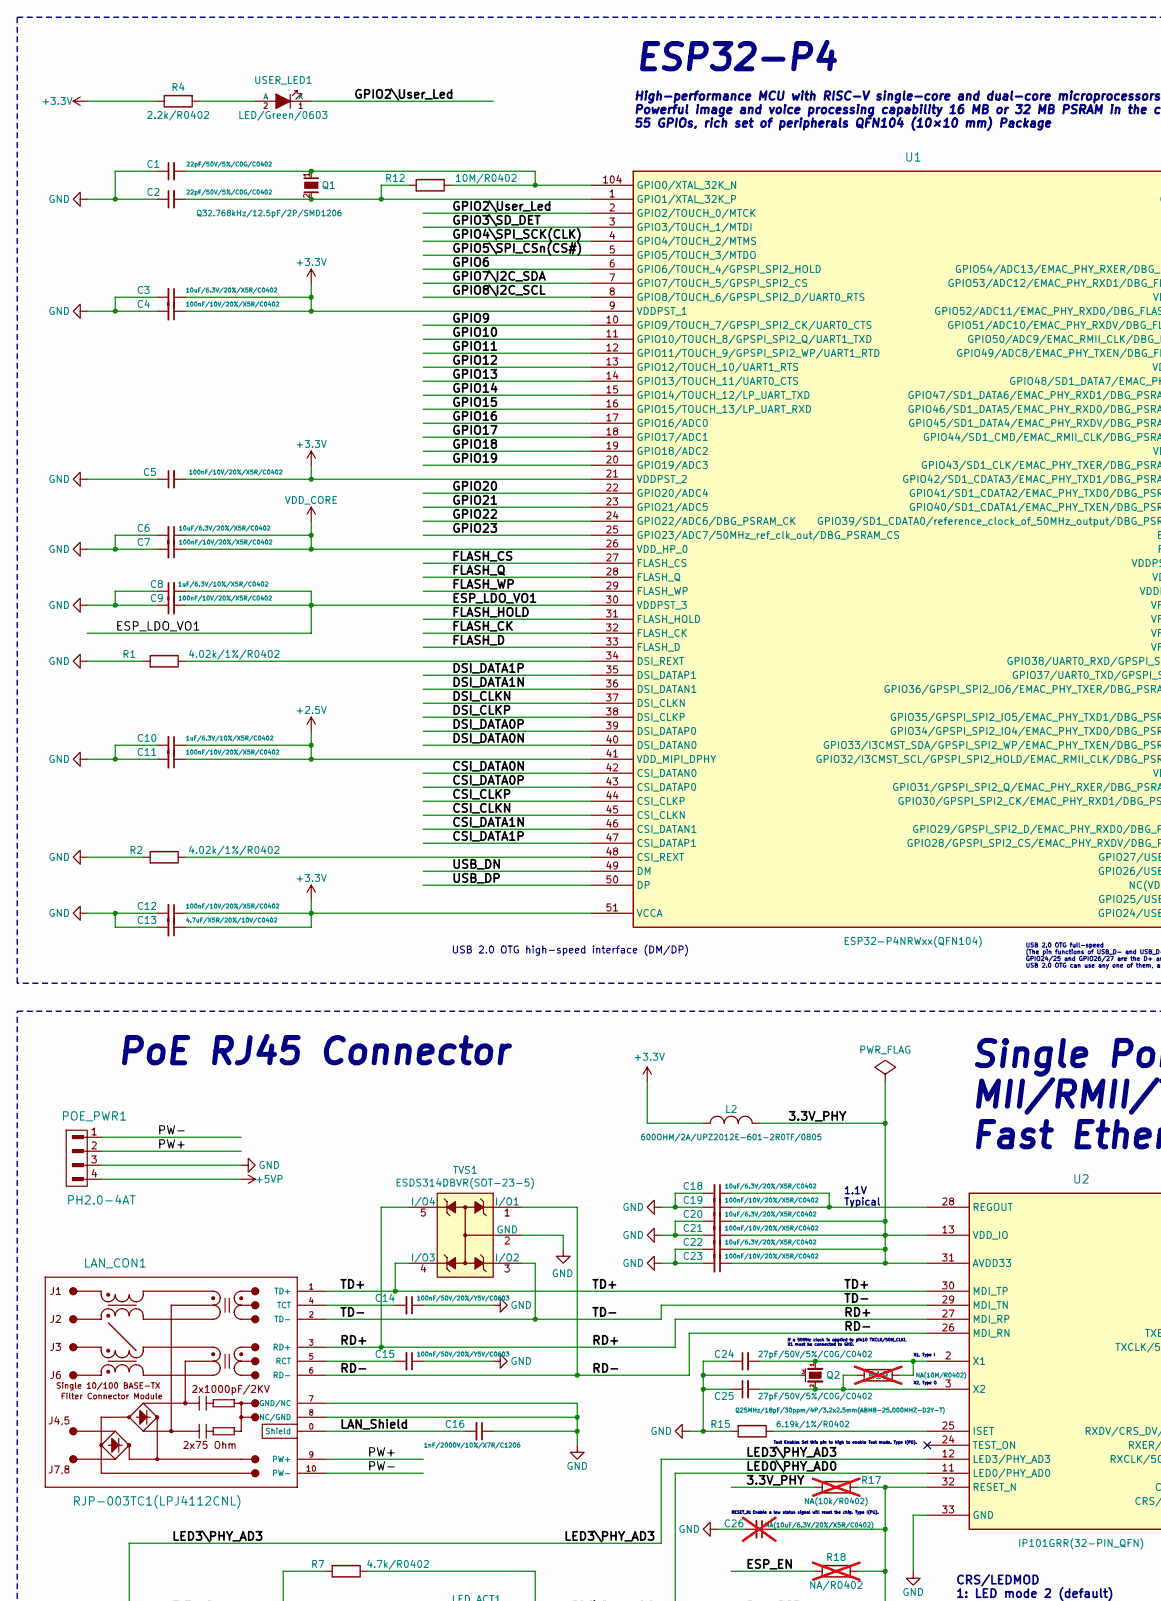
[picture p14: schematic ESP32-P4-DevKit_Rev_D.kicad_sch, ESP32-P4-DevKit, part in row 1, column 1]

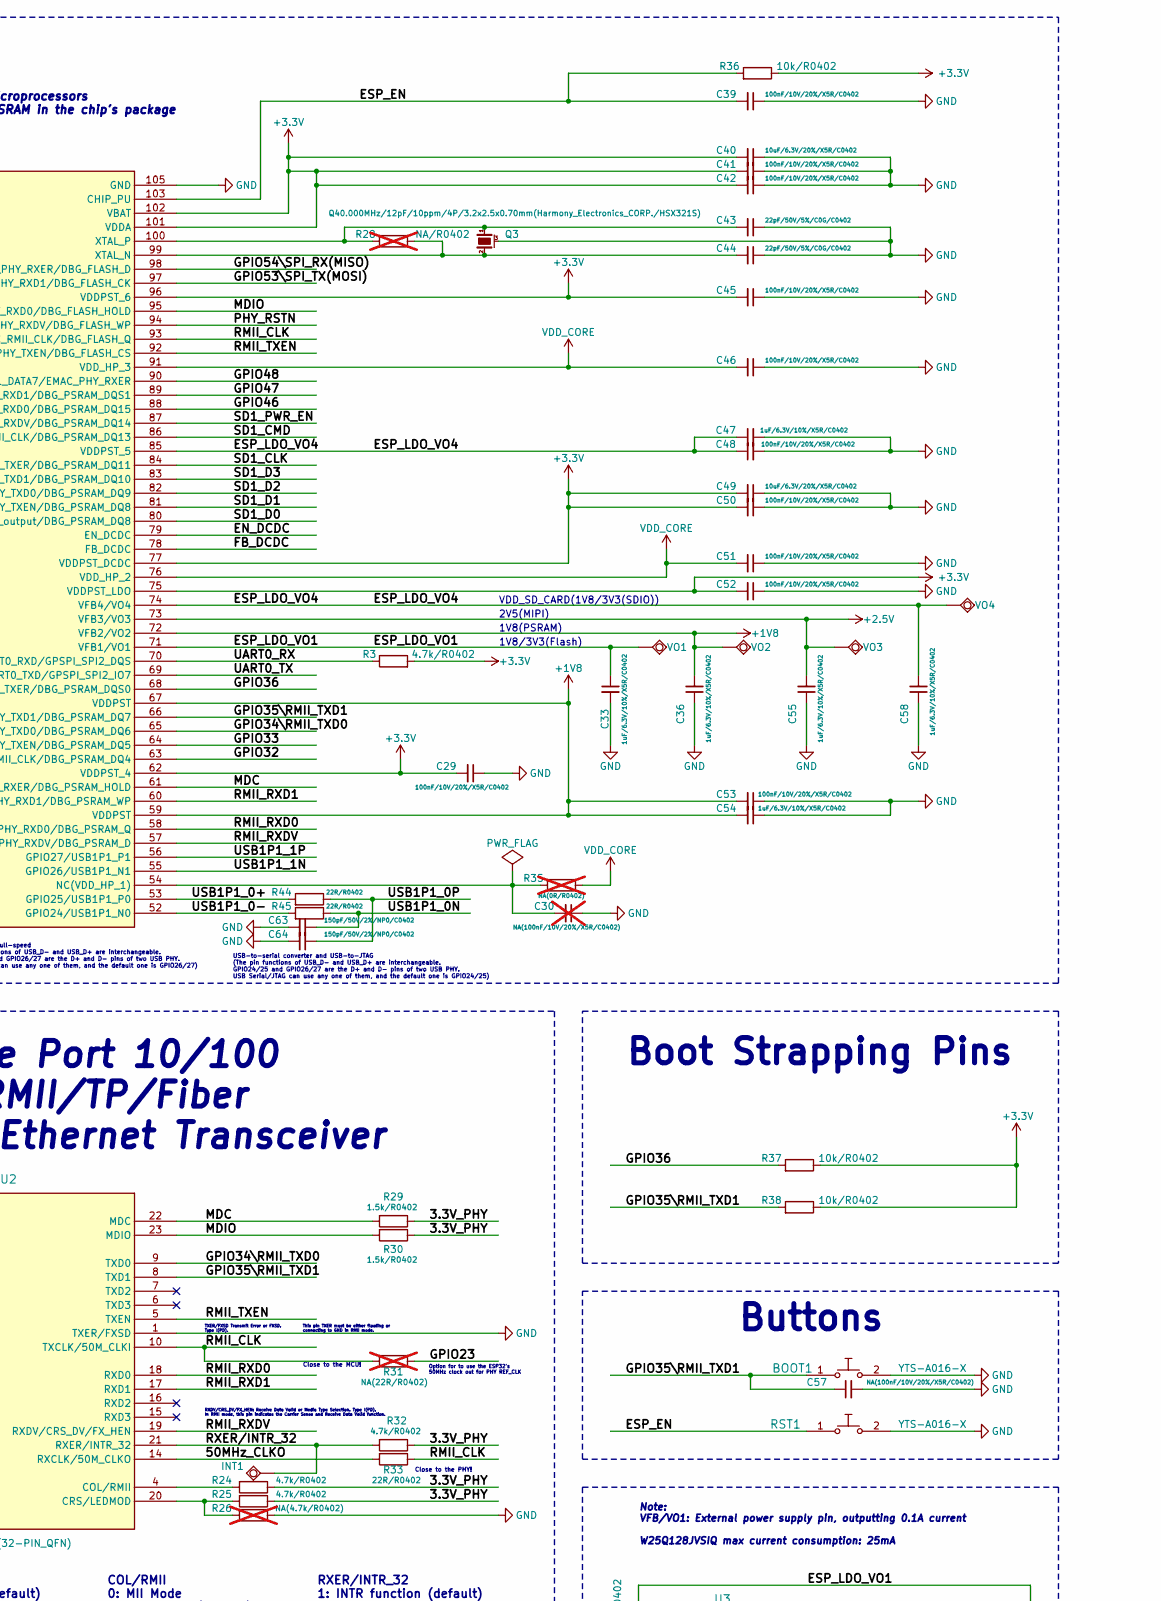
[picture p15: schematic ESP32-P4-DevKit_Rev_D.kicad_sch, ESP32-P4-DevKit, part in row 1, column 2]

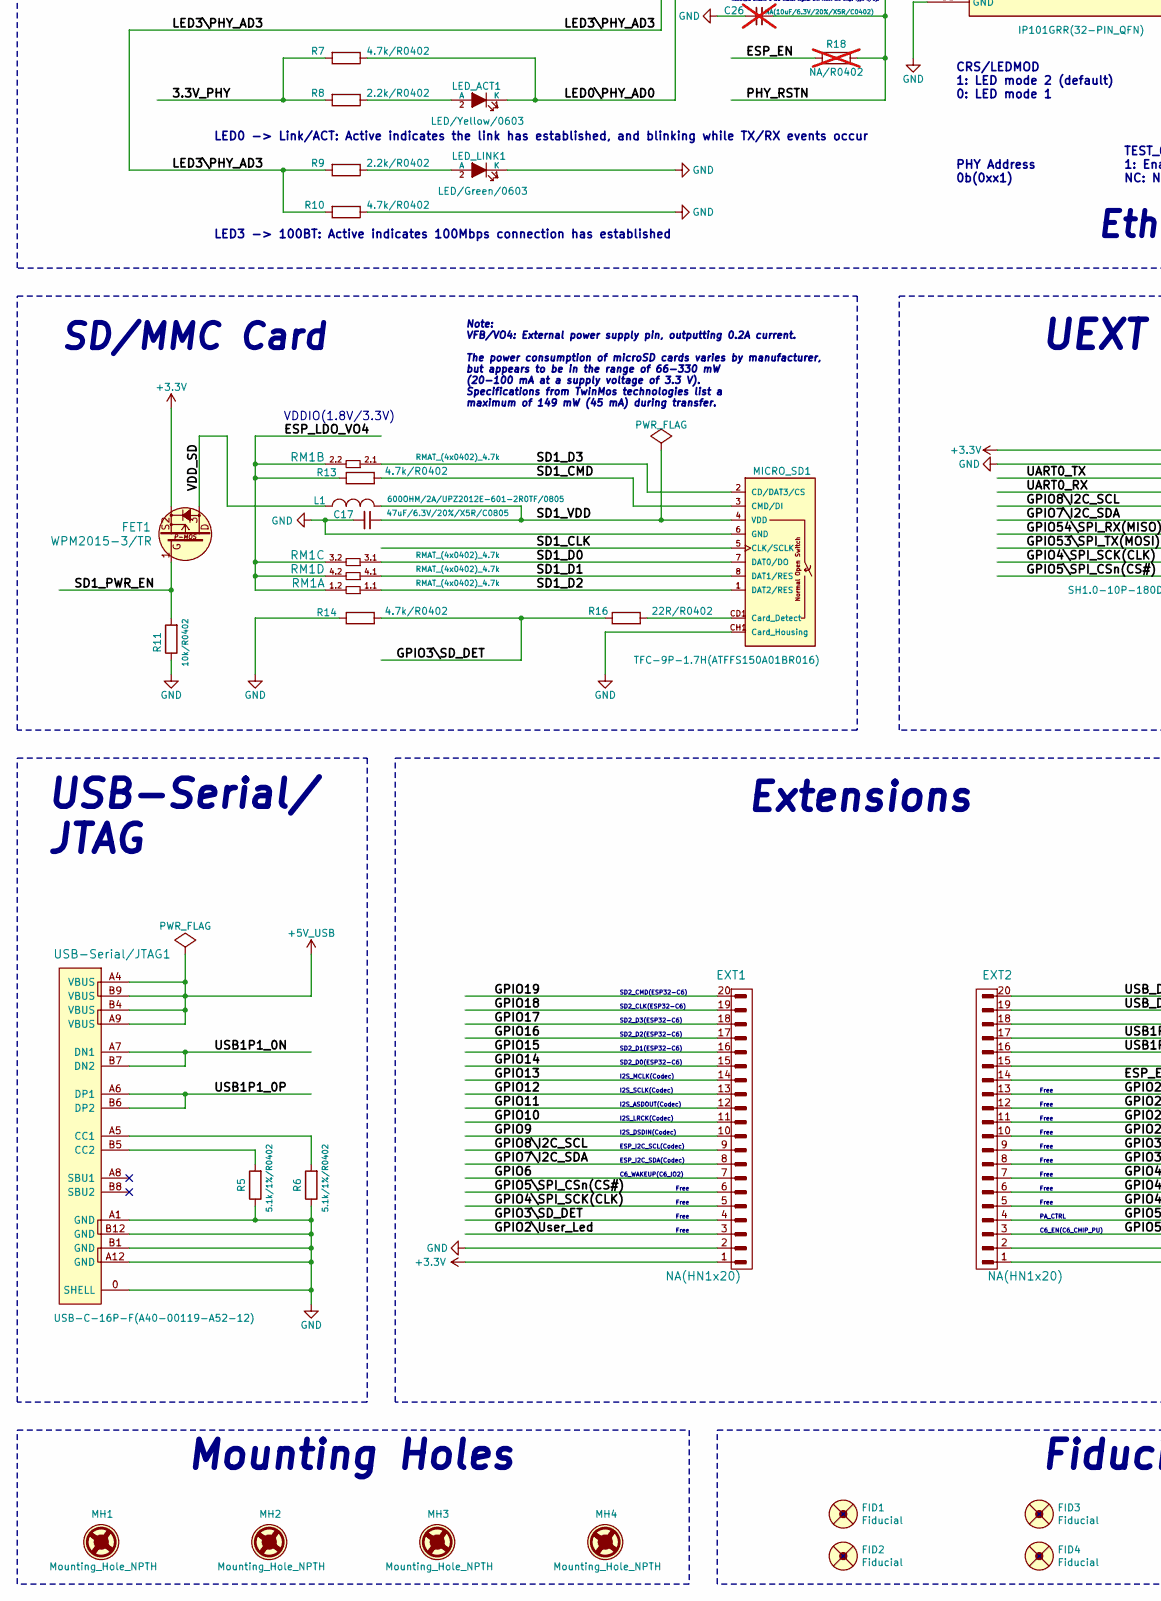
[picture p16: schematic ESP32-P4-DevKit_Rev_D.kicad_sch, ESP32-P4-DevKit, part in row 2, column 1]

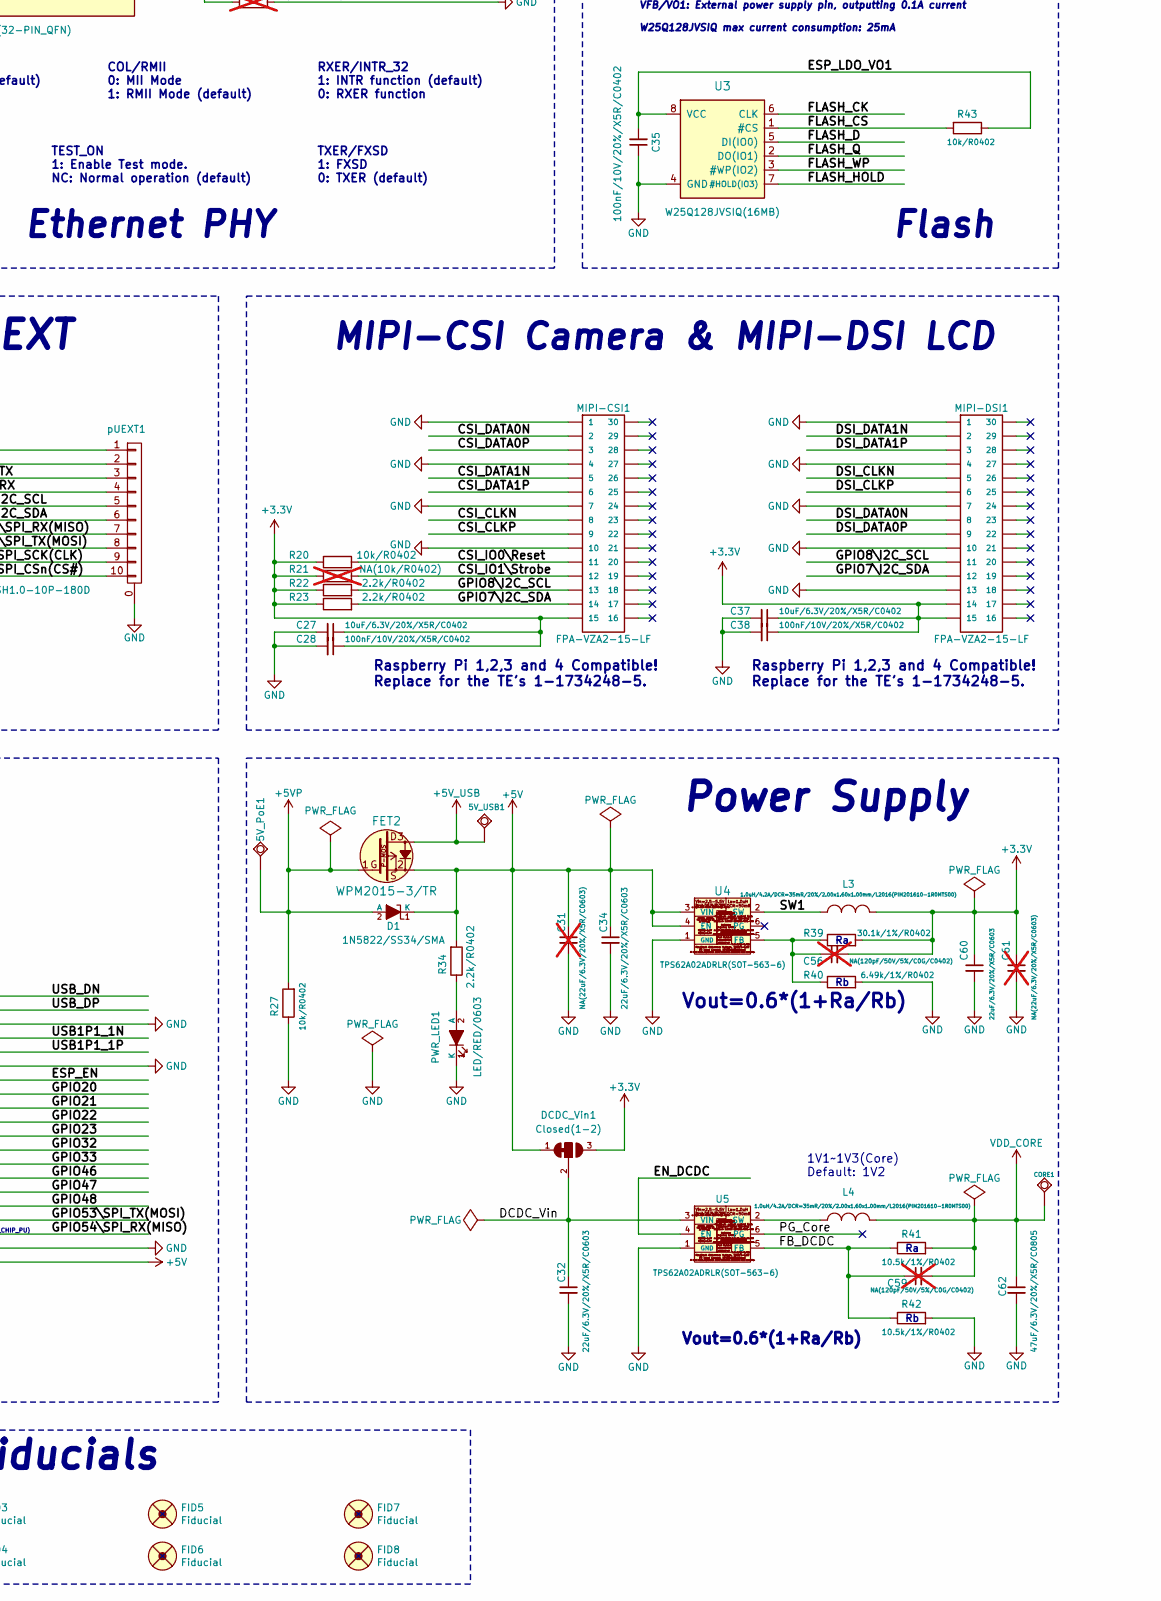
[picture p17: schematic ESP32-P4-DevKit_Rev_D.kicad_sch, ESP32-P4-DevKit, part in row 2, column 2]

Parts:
5V_PoE1, 5V_USB1: TESTPAD; TESTPAD_40-ROUND
BOOT1: YTS-A016-X
C1, C2, C43, C44: 22pF/50V/5%/C0G/C0402; C_0402_5MIL_DWS
C3, C6, C18, C20, C22, C27, C37, C40, C49: 10uF/6.3V/20%/X5R/C0402; C_0402_5MIL_DWS
C4, C5, C7, C9, C11, C12, C19, C21, C23, C28, C29, C35, C38, C39, C41, C42, C45, C46, C48, C50, C51, C52, C53: 100nF/10V/20%/X5R/C0402; C_0402_5MIL_DWS
C8, C10, C33, C36, C47, C54, C55, C58: 1uF/6.3V/10%/X5R/C0402; C_0402_5MIL_DWS
C13: 4.7uF/X5R/20%/10V/C0402; C_0402_5MIL_DWS
C14, C15: 100nF/50V/20%/Y5V/C0603; C_0603_5MIL_DWS
C16: 1nF/2000V/10%/X7R/C1206; C_1206_5MIL_DWS_ISO
C17, C62: 47uF/6.3V/20%/X5R/C0805; C_0805_5MIL_DWS
C24, C25: 27pF/50V/5%/C0G/C0402; C_0402_5MIL_DWS
C26: NA(10uF/6.3V/20%/X5R/C0402); C_0402_5MIL_DWS; not fitted
C30: NA(100nF/10V/20%/X5R/C0402); C_0402_5MIL_DWS; not fitted
C31, C61: NA(22uF/6.3V/20%/X5R/C0603); C_0603_5MIL_DWS; not fitted
C32, C34, C60: 22uF/6.3V/20%/X5R/C0603; C_0603_5MIL_DWS
C56, C59: NA(120pF/50V/5%/C0G/C0402); C_0402_5MIL_DWS; not fitted
C57: NA(100nF/10V/20%/X5R/C0402); C_0402_5MIL_DWS
C63, C64: 150pF/50V/2%/NP0/C0402; C_0402_5MIL_DWS
CORE1: TESTPAD; TESTPAD_40-ROUND
D1: 1N5822/SS34/SMA; SMA-KA
DCDC_Vin1: Closed(1-2); SJ_2_SMALL_12_TIED
EXT1, EXT2: NA(HN1x20); HN1x20
FET1, FET2: WPM2015-3/TR; SOT23
FID1, FID3, FID5, FID7: Fiducial; Fiducial1x3
FID2, FID4, FID6, FID8: Fiducial; Fiducial1x3_Paste
INT1: TESTPAD; TESTPAD_40-ROUND
L1, L2: 600OHM/2A/UPZ2012E-601-2R0TF/0805; L_0805_5MIL_DWS
L3, L4: 1.0uH/4.2A/DCR=35mR/20%/2.00x1.60x1.00mm/L2016(PI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; L_2016_MM
LAN_CON1: RJP-003TC1(LPJ4112CNL)
LED_ACT1: LED/Yellow/0603; LED_0603_KA
LED_LINK1: LED/Green/0603; LED_0603_KA
MH1, MH2, MH3, MH4: Mounting_Hole_NPTH; Mounting_Hole_Drill-3.3mm_Clerance-7mm
MICRO_SD1: TFC-9P-1.7H(ATFFS150A01BR016); uSD(TFC-9P-1.xH(ATFFS150A01BR016))
MIPI-CSI1: FPA-VZA2-15-LF; TE_1-1734248-5
MIPI-DSI1: FPA-VZA2-15-LF; TE_1-1734248-5
POE_PWR1: PH2.0-4AT; PH2.0-4PLB
PWR_LED1: LED/RED/0603; LED_0603_KA
Q1: Q32.768kHz/12.5pF/2P/SMD1206; CM7V-T1A(Crystal_Package-1206_3.20x1.50x0.65mm)
Q2: Q25MHz/18pF/30ppm/4P/3.2x2.5mm(ABM8-25.000MHZ-D2Y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; TSX-3.2x2.5mm_GND(3)
Q3: Q40.000MHz/12pF/10ppm/4P/3.2x2.5x0.70mm(Harmony_E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; TSX-3.2x2.5mm_GND(3)
R1, R2: 4.02k/1%/R0402; R_0402_5MIL_DWS
R3, R7, R10, R13, R14, R24, R25, R32: 4.7k/R0402; R_0402_5MIL_DWS
R4, R8, R9, R22, R23, R34: 2.2k/R0402; R_0402_5MIL_DWS
R5, R6: 5.1k/1%/R0402; R_0402_5MIL_DWS
R11, R20, R27, R36, R37, R38, R43: 10k/R0402; R_0402_5MIL_DWS
R12: 10M/R0402; R_0402_5MIL_DWS
R15: 6.19k/1%/R0402; R_0402_5MIL_DWS
R16, R33, R44, R45: 22R/R0402; R_0402_5MIL_DWS
R17, R21: NA(10k/R0402); R_0402_5MIL_DWS; not fitted
R18, R28: NA/R0402; R_0402_5MIL_DWS; not fitted
R19: NA(10M/R0402); R_0402_5MIL_DWS; not fitted
R26: NA(4.7k/R0402); R_0402_5MIL_DWS; not fitted
R29, R30: 1.5k/R0402; R_0402_5MIL_DWS
R31: NA(22R/R0402); R_0402_5MIL_DWS; not fitted
R35: NA(0R/R0402); R_0402_5MIL_DWS; not fitted
R39: 30.1k/1%/R0402; R_0402_5MIL_DWS
R40: 6.49k/1%/R0402; R_0402_5MIL_DWS
R41, R42: 10.5k/1%/R0402; R_0402_5MIL_DWS
RM1: RMAT_(4x0402)_4.7k; RA0805_(4X0402)_xx_BIGGEROUTPADS
RST1: YTS-A016-X
TVS1: ESDS314DBVR(SOT-23-5); SOT-23-5
U1: ESP32-P4NRWxx(QFN104); QFN104_10mm×10mm_Pitch_0.35mm
U2: IP101GRR(32-PIN_QFN); QFN32_EP(33)_4.00x4.00x0.80mm_Pitch_0.40mm
U3: W25Q128JVSIQ(16MB); SO-8_208mil
U4, U5: TPS62A02ADRLR(SOT-563-6); SOT-563-6
USB-Serial/JTAG1: USB-C-16P-F(A40-00119-A52-12); USB2.0_TYPE-C(A40-00119-A52-12)_Paste
USER_LED1: LED/Green/0603; LED_0603_KA
VO1, VO2, VO3, VO4: TESTPAD; TESTPAD_40-ROUND
pUEXT1: SH1.0-10P-180D; BM10B-SRSS-TB

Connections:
+1V8: C36.2, C53.2, C54.2, U1.59 (VDDPST), U1.67 (VDDPST), U1.72 (VFB2/VO2), VO2.1 (Pad)
+2.5V: C10.1, C11.1, C55.2, U1.41 (VDD_MIPI_DPHY), U1.73 (VFB3/VO3), VO3.1 (Pad)
+3.3V: C3.1, C4.1, C5.2, C12.1, C13.1, C27.1, C28.1, C29.2, C37.1, C38.1, C40.2, C41.2, C42.2, C45.2, C49.2, C50.2, C52.2, C56.2, C60.1, C61.1, DCDC_Vin1.3, EXT1.1, FET1.2, L2.1, L3.2, MIPI-CSI1.15, MIPI-DSI1.14, MIPI-DSI1.15, R3.2, R4.1, R20.1, R21.1, R22.1, R23.1, R36.1, R37.1, R38.1, R39.2, U1.9 (VDDPST_1), U1.21 (VDDPST_2), U1.51 (VCCA), U1.62 (VDDPST_4), U1.75 (VDDPST_LDO), U1.77 (VDDPST_DCDC), U1.96 (VDDPST_6), U1.101 (VDDA), U1.102 (VBAT), pUEXT1.1
+5V: C31.1, C34.1, D1.1 (K), DCDC_Vin1.1, EXT2.1, FET2.2, R34.2, U4.3 (VIN), U4.4 (EN)
+5VP: 5V_PoE1.1 (Pad), D1.2 (A), FET2.1, POE_PWR1.4, R27.2
+5V_USB: 5V_USB1.1 (Pad), FET2.3, USB-Serial/JTAG1.A4 (VBUS), USB-Serial/JTAG1.A9 (VBUS), USB-Serial/JTAG1.B4 (VBUS), USB-Serial/JTAG1.B9 (VBUS)
/3.3V_PHY: C20.1, C21.1, C22.1, C23.1, L2.2, R7.2, R8.2, R17.1, R24.1, R25.1, R29.1, R30.1, R32.1, U2.13 (VDD_IO), U2.31 (AVDD33)
/50MHz_CLKO: R33.2, U2.14 (RXCLK/50M_CLKO)
/CSI_CLKN: MIPI-CSI1.8, U1.45 (CSI_CLKN)
/CSI_CLKP: MIPI-CSI1.9, U1.44 (CSI_CLKP)
/CSI_DATA0N: MIPI-CSI1.2, U1.42 (CSI_DATAN0)
/CSI_DATA0P: MIPI-CSI1.3, U1.43 (CSI_DATAP0)
/CSI_DATA1N: MIPI-CSI1.5, U1.46 (CSI_DATAN1)
/CSI_DATA1P: MIPI-CSI1.6, U1.47 (CSI_DATAP1)
/CSI_IO0\Reset: MIPI-CSI1.11, R20.2
/CSI_IO1\Strobe: MIPI-CSI1.12, R21.2
/DCDC_Vin: C32.1, DCDC_Vin1.2, U5.3 (VIN)
/DSI_CLKN: MIPI-DSI1.5, U1.37 (DSI_CLKN)
/DSI_CLKP: MIPI-DSI1.6, U1.38 (DSI_CLKP)
/DSI_DATA0N: MIPI-DSI1.8, U1.40 (DSI_DATAN0)
/DSI_DATA0P: MIPI-DSI1.9, U1.39 (DSI_DATAP0)
/DSI_DATA1N: MIPI-DSI1.2, U1.36 (DSI_DATAN1)
/DSI_DATA1P: MIPI-DSI1.3, U1.35 (DSI_DATAP1)
/EN_DCDC: U1.79 (EN_DCDC), U5.4 (EN)
/ESP_EN: C39.2, EXT2.14, R18.1, R36.2, RST1.1, U1.103 (CHIP_PU)
/ESP_LDO_VO1: C8.2, C9.2, C33.1, C35.2, R43.1, U1.30 (VDDPST_3), U1.71 (VFB1/VO1), U3.8 (VCC), VO1.1 (Pad)
/ESP_LDO_VO4: C47.1, C48.1, C58.2, R13.1, RM1.1.2, RM1.2.2, RM1.3.2, RM1.4.2, U1.74 (VFB4/VO4), U1.85 (VDDPST_5), VO4.1 (Pad)
/FB_DCDC: C59.1, R41.1, R42.1, U1.78 (FB_DCDC), U5.5 (FB)
/FLASH_CK: U1.32 (FLASH_CK), U3.6 (CLK)
/FLASH_CS: R43.2, U1.27 (FLASH_CS), U3.1 (#CS)
/FLASH_D: U1.33 (FLASH_D), U3.5 (DI(IO0))
/FLASH_HOLD: U1.31 (FLASH_HOLD), U3.7 (#HOLD(IO3))
/FLASH_Q: U1.28 (FLASH_Q), U3.2 (DO(IO1))
/FLASH_WP: U1.29 (FLASH_WP), U3.3 (#WP(IO2))
/GPIO2\User_Led: EXT1.3, U1.2 (GPIO2/TOUCH_0/MTCK), USER_LED1.1 (K)
/GPIO3\SD_DET: EXT1.4, R14.2, R16.1, U1.3 (GPIO3/TOUCH_1/MTDI)
/GPIO4\SPI_SCK(CLK): EXT1.5, U1.4 (GPIO4/TOUCH_2/MTMS), pUEXT1.9
/GPIO5\SPI_CSn(CS#): EXT1.6, U1.5 (GPIO5/TOUCH_3/MTDO), pUEXT1.10
/GPIO6: EXT1.7, U1.6 (GPIO6/TOUCH_4/GPSPI_SPI2_HOLD)
/GPIO7\I2C_SDA: EXT1.8, MIPI-CSI1.14, MIPI-DSI1.12, R23.2, U1.7 (GPIO7/TOUCH_5/GPSPI_SPI2_CS), pUEXT1.6
/GPIO8\I2C_SCL: EXT1.9, MIPI-CSI1.13, MIPI-DSI1.11, R22.2, U1.8 (GPIO8/TOUCH_6/GPSPI_SPI2_D/UART0_RTS), pUEXT1.5
/GPIO9: EXT1.10, U1.10 (GPIO9/TOUCH_7/GPSPI_SPI2_CK/UART0_CTS)
/GPIO10: EXT1.11, U1.11 (GPIO10/TOUCH_8/GPSPI_SPI2_Q/UART1_TXD)
/GPIO11: EXT1.12, U1.12 (GPIO11/TOUCH_9/GPSPI_SPI2_WP/UART1_RTD)
/GPIO12: EXT1.13, U1.13 (GPIO12/TOUCH_10/UART1_RTS)
/GPIO13: EXT1.14, U1.14 (GPIO13/TOUCH_11/UART0_CTS)
/GPIO14: EXT1.15, U1.15 (GPIO14/TOUCH_12/LP_UART_TXD)
/GPIO15: EXT1.16, U1.16 (GPIO15/TOUCH_13/LP_UART_RXD)
/GPIO16: EXT1.17, U1.17 (GPIO16/ADC0)
/GPIO17: EXT1.18, U1.18 (GPIO17/ADC1)
/GPIO18: EXT1.19, U1.19 (GPIO18/ADC2)
/GPIO19: EXT1.20, U1.20 (GPIO19/ADC3)
/GPIO20: EXT2.13, U1.22 (GPIO20/ADC4)
/GPIO21: EXT2.12, U1.23 (GPIO21/ADC5)
/GPIO22: EXT2.11, U1.24 (GPIO22/ADC6/DBG_PSRAM_CK)
/GPIO23: EXT2.10, R31.1, U1.25 (GPIO23/ADC7/50MHz_ref_clk_out/DBG_PSRAM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)
/GPIO32: EXT2.9, U1.63 (GPIO32/I3CMST_SCL/GPSPI_SPI2_HOLD/EMAC_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)
/GPIO33: EXT2.8, U1.64 (GPIO33/I3CMST_SDA/GPSPI_SPI2_WP/EMAC_PH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)
/GPIO34\RMII_TXD0: U1.65 (GPIO34/GPSPI_SPI2_IO4/EMAC_PHY_TXD0/DBG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), U2.9 (TXD0)
/GPIO35\RMII_TXD1: BOOT1.1, C57.1, R38.2, U1.66 (GPIO35/GPSPI_SPI2_IO5/EMAC_PHY_TXD1/DBG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), U2.8 (TXD1)
/GPIO36: R37.2, U1.68 (GPIO36/GPSPI_SPI2_IO6/EMAC_PHY_TXER/DBG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)
/GPIO46: EXT2.7, U1.88 (GPIO46/SD1_DATA5/EMAC_PHY_RXD0/DBG_PSRA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)
/GPIO47: EXT2.6, U1.89 (GPIO47/SD1_DATA6/EMAC_PHY_RXD1/DBG_PSRA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)
/GPIO48: EXT2.5, U1.90 (GPIO48/SD1_DATA7/EMAC_PHY_RXER)
/GPIO53\SPI_TX(MOSI): EXT2.4, U1.97 (GPIO53/ADC12/EMAC_PHY_RXD1/DBG_FLASH_CK), pUEXT1.8
/GPIO54\SPI_RX(MISO): EXT2.3, U1.98 (GPIO54/ADC13/EMAC_PHY_RXER/DBG_FLASH_D), pUEXT1.7
/LAN_Shield: C16.2, LAN_CON1.0 (Shield)
/LED0\PHY_AD0: LED_ACT1.1 (K), R7.1, U2.11 (LED0/PHY_AD0)
/LED3\PHY_AD3: R9.2, R10.2, U2.12 (LED3/PHY_AD3)
/MDC: R29.2, U1.61 (GPIO31/GPSPI_SPI2_Q/EMAC_PHY_RXER/DBG_P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), U2.22 (MDC)
/MDIO: R30.2, U1.95 (GPIO52/ADC11/EMAC_PHY_RXD0/DBG_FLASH_HO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), U2.23 (MDIO)
/PG_Core: U5.6 (PG)
/PHY_RSTN: C26.1, R17.2, R18.2, U1.94 (GPIO51/ADC10/EMAC_PHY_RXDV/DBG_FLASH_WP), U2.32 (RESET_N)
/PW+: LAN_CON1.9 (PW+), POE_PWR1.2
/PW-: LAN_CON1.10 (PW-), POE_PWR1.1
/RD+: LAN_CON1.3 (RD+), TVS1.5 (I/O4), U2.27 (MDI_RP)
/RD-: LAN_CON1.6 (RD-), TVS1.1 (I/O1), U2.26 (MDI_RN)
/RMII_CLK: R31.2, R33.1, U1.93 (GPIO50/ADC9/EMAC_RMII_CLK/DBG_FLASH_Q), U2.10 (TXCLK/50M_CLKI)
/RMII_RXD0: U1.58 (GPIO29/GPSPI_SPI2_D/EMAC_PHY_RXD0/DBG_P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), U2.18 (RXD0)
/RMII_RXD1: U1.60 (GPIO30/GPSPI_SPI2_CK/EMAC_PHY_RXD1/DBG_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), U2.17 (RXD1)
/RMII_RXDV: U1.57 (GPIO28/GPSPI_SPI2_CS/EMAC_PHY_RXDV/DBG_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), U2.19 (RXDV/CRS_DV/FX_HEN)
/RMII_TXEN: U1.92 (GPIO49/ADC8/EMAC_PHY_TXEN/DBG_FLASH_CS), U2.5 (TXEN)
/RXER/INTR_32: INT1.1 (Pad), R32.2, U2.21 (RXER/INTR_32)
/SD1_CLK: MICRO_SD1.5 (CLK/SCLK), U1.84 (GPIO43/SD1_CLK/EMAC_PHY_TXER/DBG_PSRAM_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)
/SD1_CMD: MICRO_SD1.3 (CMD/DI), R13.2, U1.86 (GPIO44/SD1_CMD/EMAC_RMII_CLK/DBG_PSRAM_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)
/SD1_D0: MICRO_SD1.7 (DAT0/DO), RM1.3.1, U1.80 (GPIO39/SD1_CDATA0/reference_clock_of_50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)
/SD1_D1: MICRO_SD1.8 (DAT1/RES), RM1.4.1, U1.81 (GPIO40/SD1_CDATA1/EMAC_PHY_TXEN/DBG_PSR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)
/SD1_D2: MICRO_SD1.1 (DAT2/RES), RM1.1.1, U1.82 (GPIO41/SD1_CDATA2/EMAC_PHY_TXD0/DBG_PSR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)
/SD1_D3: MICRO_SD1.2 (CD/DAT3/CS), RM1.2.1, U1.83 (GPIO42/SD1_CDATA3/EMAC_PHY_TXD1/DBG_PSR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)
/SD1_PWR_EN: FET1.1, R11.2, U1.87 (GPIO45/SD1_DATA4/EMAC_PHY_RXDV/DBG_PSRA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)
/SD1_VDD: C17.1, L1.2, MICRO_SD1.4 (VDD)
/SW1: L3.1, U4.2 (SW)
/TD+: LAN_CON1.1 (TD+), TVS1.4 (I/O3), U2.30 (MDI_TP)
/TD-: LAN_CON1.2 (TD-), TVS1.3 (I/O2), U2.29 (MDI_TN)
/UART0_RX: R3.1, U1.70 (GPIO38/UART0_RXD/GPSPI_SPI2_DQS), pUEXT1.4
/UART0_TX: U1.69 (GPIO37/UART0_TXD/GPSPI_SPI2_IO7), pUEXT1.3
/USB1P1_0+: R44.2, U1.53 (GPIO25/USB1P1_P0)
/USB1P1_0-: R45.2, U1.52 (GPIO24/USB1P1_N0)
/USB1P1_0N: C63.1, R45.1, USB-Serial/JTAG1.A7 (DN1), USB-Serial/JTAG1.B7 (DN2)
/USB1P1_0P: C64.1, R44.1, USB-Serial/JTAG1.A6 (DP1), USB-Serial/JTAG1.B6 (DP2)
/USB1P1_1N: EXT2.17, U1.55 (GPIO26/USB1P1_N1)
/USB1P1_1P: EXT2.16, U1.56 (GPIO27/USB1P1_P1)
/USB_DN: EXT2.20, U1.49 (DM)
/USB_DP: EXT2.19, U1.50 (DP)
/VDD_SD: FET1.3, L1.1
GND: BOOT1.2, C1.1, C2.1, C3.2, C4.2, C5.1, C6.2, C7.2, C8.1, C9.1, C10.2, C11.2, C12.2, C13.2, C14.1, C15.1, C16.1, C17.2, C18.2, C19.2, C20.2, C21.2, C22.2, C23.2, C24.1, C25.1, C26.2, C27.2, C28.2, C29.1, C30.1, C31.2, C32.2, C33.2, C34.2, C35.1, C36.1, C37.2, C38.2, C39.1, C40.1, C41.1, C42.1, C43.1, C44.1, C45.1, C46.1, C47.2, C48.2, C49.1, C50.1, C51.1, C52.1, C53.1, C54.1, C55.1, C57.2, C58.1, C60.2, C61.2, C62.2, C63.2, C64.2, EXT1.2, EXT2.2, EXT2.15, EXT2.18, LAN_CON1.7 (GND/NC), LAN_CON1.8 (NC/GND), LED_LINK1.1 (K), MICRO_SD1.6 (GND), MICRO_SD1.CH1 (Card_Housing), MIPI-CSI1.1, MIPI-CSI1.4, MIPI-CSI1.7, MIPI-CSI1.10, MIPI-DSI1.1, MIPI-DSI1.4, MIPI-DSI1.7, MIPI-DSI1.10, MIPI-DSI1.13, POE_PWR1.3, PWR_LED1.1 (K), Q2.3 (case), Q3.3 (case), R1.2, R2.2, R5.1, R6.1, R10.1, R11.1, R14.1, R15.2, R26.1, R27.1, R40.2, R42.2, RST1.2, TVS1.2 (GND), U1.105 (GND), U2.1 (TXER/FXSD), U2.33 (GND), U3.4 (GND), U4.1 (GND), U5.1 (GND), USB-Serial/JTAG1.0 (SHELL), USB-Serial/JTAG1.A1 (GND), USB-Serial/JTAG1.A12 (GND), USB-Serial/JTAG1.B1 (GND), USB-Serial/JTAG1.B12 (GND), pUEXT1.0, pUEXT1.2
unnamed: C15.2, LAN_CON1.5 (RCT)
unnamed: C14.2, LAN_CON1.4 (TCT)
unnamed: LED_ACT1.2 (A), R8.1
unnamed: LED_LINK1.2 (A), R9.1
unnamed: MICRO_SD1.CD1 (Card_Detect), R16.2
unnamed: PWR_LED1.2 (A), R34.1
unnamed: R2.1, U1.48 (CSI_REXT)
unnamed: R1.1, U1.34 (DSI_REXT)
unnamed: C1.2, Q1.1, R12.1, U1.104 (GPIO0/XTAL_32K_N)
unnamed: C2.2, Q1.2, R12.2, U1.1 (GPIO1/XTAL_32K_P)
unnamed: C30.2, R35.2, U1.54 (NC(VDD_HP_1))
unnamed: C44.2, Q3.2, R28.2, U1.99 (XTAL_N)
unnamed: C43.2, Q3.1, R28.1, U1.100 (XTAL_P)
unnamed: R24.2, U2.4 (COL/RMII)
unnamed: R25.2, R26.2, U2.20 (CRS/LEDMOD)
unnamed: R15.1, U2.25 (ISET)
unnamed: C18.1, C19.1, U2.28 (REGOUT)
unnamed: C24.2, Q2.1, R19.2, U2.2 (X1)
unnamed: C25.2, Q2.2, R19.1, U2.3 (X2)
unnamed: C56.1, R39.1, R40.1, U4.5 (FB)
unnamed: L4.1, U5.2 (SW)
unnamed: R6.2, USB-Serial/JTAG1.A5 (CC1)
unnamed: R5.2, USB-Serial/JTAG1.B5 (CC2)
unnamed: R4.2, USER_LED1.2 (A)
VDD_CORE: C6.1, C7.1, C46.2, C51.2, C59.2, C62.1, CORE1.1 (Pad), L4.2, R35.1, R41.2, U1.26 (VDD_HP_0), U1.76 (VDD_HP_2), U1.91 (VDD_HP_3)

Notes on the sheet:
Note: VFB/VO1: External power supply pin, outputting 0.1A current W25Q128JVSIQ max current consumption: 25mA
TXER/FXSD Transmit Error or FXSD. Type I(PD).
I2S_LRCK(Codec)
USB-to-serial converter and USB-to-JTAG (The pin functions of USB_D- and USB_D+ are interchangeable. GPIO24/25 and GPIO26/27 are the D+ and D- pins of two USB PHY. USB Serial/JTAG can use any one of them, and the default one is GPIO24/25)
Power Supply
Vout=0.6*(1+Ra/Rb)
I2S_DSDIN(Codec)
Free
SD2_D2(ESP32-C6)
Boot Strapping Pins
Mounting Holes
LED0 -> Link/ACT: Active indicates the link has established, and blinking while TX/RX events occur
SD2_D1(ESP32-C6)
RXER/INTR_32 1: INTR function (default) 0: RXER function
COL/RMII 0: MII Mode 1: RMII Mode (default)
This pin TXER must be either floating or connecting to GND in RMII mode.
I2S_SCLK(Codec)
Close to the MCU!
RXDV/CRS_DV/FX_HEN: Receive Data Valid or Media Type Selection. Type I(PD). In RMII mode, this pin indicates the Carrier Sense and Receive Data Valid function.
SD2_CLK(ESP32-C6)
TXER/FXSD 1: FXSD 0: TXER (default)
TEST_ON 1: Enable Test mode. NC: Normal operation (default)
Ethernet PHY
SD2_CMD(ESP32-C6)
Test Enable: Set this pin to high to enable Test mode. Type I(PD).
High-performance MCU with RISC-V single-core and dual-core microprocessors Powerful image and voice processing capability 16 MB or 32 MB PSRAM in the chip's package 55 GPIOs, rich set of peripherals QFN104 (10×10 mm) Package
USB 2.0 OTG high-speed interface (DM/DP)
If a 50MHz clock is applied to pin10 TXCLK/50M_CLKI, X1 must be connected to GND.
1V8/3V3(Flash)
X2, Type O
SD2_D0(ESP32-C6)
PoE RJ45 Connector
MIPI-CSI Camera & MIPI-DSI LCD
Raspberry Pi 1,2,3 and 4 Compatible! Replace for the TE's 1-1734248-5.
RESET_N: Enable a low status signal will reset the chip. Type I(PU).
I2S_ASDOUT(Codec)
C6_WAKEUP(C6_IO2)
USB 2.0 OTG full-speed (The pin functions of USB_D- and USB_D+ are interchangeable. GPIO24/25 and GPIO26/27 are the D+ and D- pins of two USB PHY. USB 2.0 OTG can use any one of them, and the default one is GPIO26/27)
Flash
Buttons

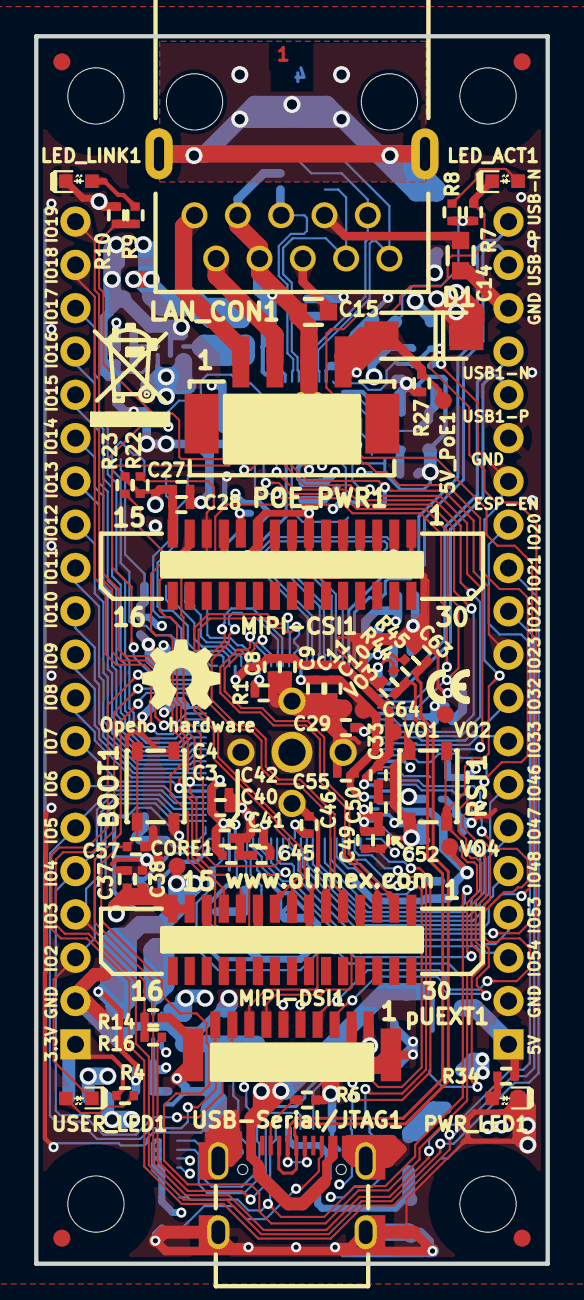
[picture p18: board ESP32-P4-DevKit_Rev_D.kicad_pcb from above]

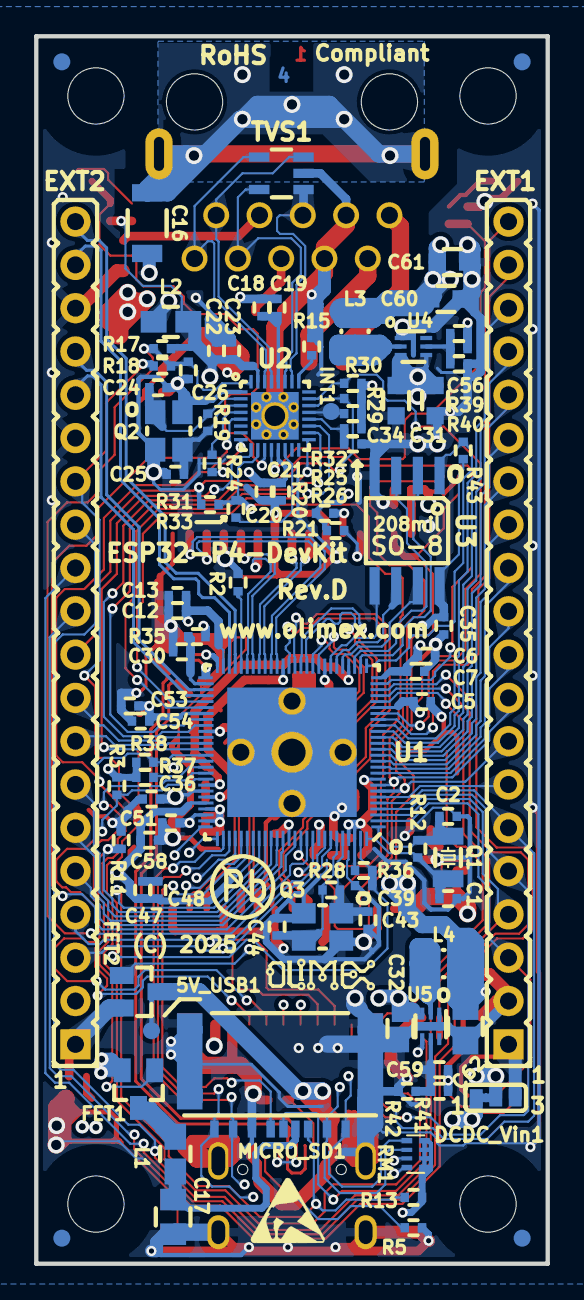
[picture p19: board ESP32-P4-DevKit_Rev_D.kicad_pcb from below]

Board: 4 copper layers, 30.0 x 72.0 mm, 168 parts (97 on the bottom side), 130 nets.

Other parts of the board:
Logo_OLIMEX_SMALL_TB: Logo_OLIMEX_SMALL_TB
Sign_Antistatic_150: Sign_Antistatic_150
Sign_CE_Small: CE_Sign_Small
Sign_OSHW_7.3x6.0mm: Sign_OSHW_7.3x6.0mm; Sign_OSHW_7.3x6.0mmn
Sign_PB-Free: Sign_PB-Free
Sign_RecycleBin_1: Sign_RecycleBin_1

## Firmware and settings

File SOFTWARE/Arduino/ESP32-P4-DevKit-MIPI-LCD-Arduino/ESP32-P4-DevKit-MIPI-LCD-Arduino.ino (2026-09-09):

/*
 * Olimex ESP32-P4-DevKit + MIPI-LCD2.8-640x480 Arduino LVGL test.
 *
 * This keeps the LCD init path from Olimex's ESP-IDF demo, but wraps it as a
 * normal Arduino sketch.
 *
 * Required Arduino IDE Tools menu settings (select these before compiling):
 *   Board:             ESP32P4 Dev Module
 *   USB Mode:          Hardware CDC and JTAG
 *   USB CDC On Boot:   Enabled (required for the Serial Monitor diagnostics)
 *   Upload Mode:       UART0 / Hardware CDC
 *   Flash Frequency:   80 MHz
 *   Flash Mode:        DIO
 *   Flash Size:        16 MB (128 Mb) -- do not use a smaller flash setting
 *   PSRAM:             Enabled -- REQUIRED for the 480x640 RGB888 framebuffer
 *   Chip Variant:      Before v3.00 for ESP32-P4 revision 1.3 boards
 *
 * With PSRAM disabled, the MIPI driver cannot allocate its 921,600-byte frame
 * buffer and startup stops with "lcd.dsi: no memory for frame buffer".
 *
 * Serial logging is enabled at 115200 baud. On Windows, copy
 * arduino-esp32-boards.local.txt as boards.local.txt before using Serial
 * Monitor; without it, closing Serial Monitor can reset the board through
 * DTR/RTS. Set OLIMEX_DEBUG_SERIAL to 0 to disable sketch logging.
 *
 * Select the display in esp_panel_board_custom_conf.h:
 *   OLIMEX_MIPI_LCD_VERSION 2: WLK2802MIPI-15P-V2 (default; no PCA9536)
 *   OLIMEX_MIPI_LCD_VERSION 1: WLK2802MIPI-15P (PCA9536 reset/backlight)
 *
 * The user LED on GPIO2 is a 1 Hz heartbeat on both the ESP32-P4-DevKit and
 * ESP32-P4-PC. Set OLIMEX_USER_LED_ACTIVE_LEVEL to LOW if a board revision
 * has an active-low LED.
 */

#include <assert.h>
#include <stdarg.h>
#include <Arduino.h>
#include <esp_heap_caps.h>
#include <esp_display_panel.hpp>
#include <lvgl.h>

#include "esp_panel_board_custom_conf.h"
#include "lvgl_v8_port.h"

using namespace esp_panel::board;
using namespace esp_panel::drivers;

// These must be macros: enum names are not evaluated by preprocessor #if.
#define TEST_MODE_DSI_PATTERN 1
#define TEST_MODE_SOFTWARE_COLOR_BARS 2
#define TEST_MODE_LVGL_UI 3

#ifndef OLIMEX_LCD_TEST_MODE
#define OLIMEX_LCD_TEST_MODE TEST_MODE_LVGL_UI
#endif

#ifndef OLIMEX_DEBUG_SERIAL
#define OLIMEX_DEBUG_SERIAL 1
#endif

#ifndef OLIMEX_USER_LED_PIN
#define OLIMEX_USER_LED_PIN 2
#endif

#ifndef OLIMEX_USER_LED_ACTIVE_LEVEL
#define OLIMEX_USER_LED_ACTIVE_LEVEL HIGH
#endif

#if OLIMEX_LCD_TEST_MODE < 1 || OLIMEX_LCD_TEST_MODE > 3
#error "Invalid OLIMEX_LCD_TEST_MODE"
#endif

static Board *board = nullptr;

static lv_obj_t *ui_screen = nullptr;
static lv_obj_t *ui_title = nullptr;
static lv_obj_t *ui_subtitle = nullptr;
static lv_obj_t *ui_status = nullptr;
static lv_obj_t *ui_versions = nullptr;
static lv_obj_t *ui_bar = nullptr;

static void debug_begin()
{
#if OLIMEX_DEBUG_SERIAL
    Serial.begin(115200);
#if ARDUINO_USB_CDC_ON_BOOT
    uint32_t start_ms = millis();
    while (!Serial && ((millis() - start_ms) < 2000)) {
        delay(10);
    }
#endif
#endif
}

static void debug_printf(const char *format, ...)
{
#if OLIMEX_DEBUG_SERIAL
    char line[192];
    va_list args;
    va_start(args, format);
    vsnprintf(line, sizeof(line), format, args);
    va_end(args);

    Serial.print(line);
#else
    (void)format;
#endif
}

static void halt_with_message(const char *message)
{
    debug_printf("%s\n", message);
    while (true) {
        delay(1000);
    }
}

static void animate_bar(void *bar, int32_t value)
{
    lv_bar_set_value(static_cast<lv_obj_t *>(bar), value, LV_ANIM_OFF);
}

static void apply_ui_palette(lv_color_t background)
{
    lv_color32_t rgb = {.full = lv_color_to32(background)};
    const uint16_t brightness = (299U * rgb.ch.red + 587U * rgb.ch.green + 114U * rgb.ch.blue) / 1000U;
    const bool is_light_background = brightness > 145;

    const lv_color_t primary = lv_color_hex(is_light_background ? 0x1B2430 : 0xF7F4E9);
    const lv_color_t secondary = lv_color_hex(is_light_background ? 0x235B59 : 0x8ED1C6);
    const lv_color_t emphasis = lv_color_hex(is_light_background ? 0x5C3A75 : 0xFFD166);
    const lv_color_t muted = lv_color_hex(is_light_background ? 0x33404A : 0xB7C3CC);
    const lv_color_t bar_background = lv_color_hex(is_light_background ? 0xF7F4E9 : 0x23313B);
    const lv_color_t bar_indicator = lv_color_hex(is_light_background ? 0x5C3A75 : 0x8ED1C6);

    // A palette change touches several objects. Suppress LVGL's intermediate
    // invalidations, then redraw the screen only once. Without this, a color
    // change can trigger several consecutive full-screen RGB888 transfers.
    lv_obj_enable_style_refresh(false);
    lv_obj_set_style_bg_color(ui_screen, background, 0);
    lv_obj_set_style_text_color(ui_title, primary, 0);
    lv_obj_set_style_text_color(ui_subtitle, secondary, 0);
    lv_obj_set_style_text_color(ui_status, emphasis, 0);
    lv_obj_set_style_text_color(ui_versions, muted, 0);
    lv_obj_set_style_bg_color(ui_bar, bar_background, LV_PART_MAIN);
    lv_obj_set_style_bg_color(ui_bar, bar_indicator, LV_PART_INDICATOR);
    lv_obj_enable_style_refresh(true);
    lv_obj_invalidate(ui_screen);
}

static void change_background(lv_timer_t *)
{
    // Use one solid update rather than a full-screen fade. A fade transfers the
    // RGB888 framebuffer in strips and can be seen as a band moving down the panel.
    static const uint32_t colors[] = {
        0x000000, // black
        0x4A4A4A, // grey
        0xB9EBC5, // light green
        0xD5C0F0, // light purple
        0xFFC1D6, // light pink
        0x243B55, // deep blue
    };
    static uint8_t color_index = 1;

    apply_ui_palette(lv_color_hex(colors[color_index]));
    color_index = (color_index + 1) % (sizeof(colors) / sizeof(colors[0]));
}

static void create_test_ui()
{
    ui_screen = lv_scr_act();
    lv_obj_set_style_bg_opa(ui_screen, LV_OPA_COVER, 0);

    ui_title = lv_label_create(ui_screen);
    lv_label_set_text(ui_title, "Olimex ESP32-P4");
    lv_obj_set_style_text_font(ui_title, &lv_font_montserrat_28, 0);
    lv_obj_align(ui_title, LV_ALIGN_CENTER, 0, -70);

    ui_subtitle = lv_label_create(ui_screen);
    lv_label_set_text(ui_subtitle, "MIPI-LCD2.8 ST7701 Arduino");
    lv_obj_set_style_text_font(ui_subtitle, &lv_font_montserrat_16, 0);
    lv_obj_align_to(ui_subtitle, ui_title, LV_ALIGN_OUT_BOTTOM_MID, 0, 12);

    ui_status = lv_label_create(ui_screen);
    lv_label_set_text(ui_status, "Display init OK");
    lv_obj_set_style_text_font(ui_status, &lv_font_montserrat_20, 0);
    lv_obj_align(ui_status, LV_ALIGN_CENTER, 0, 35);

    ui_bar = lv_bar_create(ui_screen);
    lv_obj_set_size(ui_bar, 260, 18);
    lv_bar_set_range(ui_bar, 0, 100);
    lv_bar_set_value(ui_bar, 0, LV_ANIM_OFF);
    lv_obj_align_to(ui_bar, ui_status, LV_ALIGN_OUT_BOTTOM_MID, 0, 24);

    lv_anim_t animation;
    lv_anim_init(&animation);
    lv_anim_set_var(&animation, ui_bar);
    lv_anim_set_exec_cb(&animation, animate_bar);
    lv_anim_set_values(&animation, 0, 100);
    lv_anim_set_time(&animation, 1800);
    lv_anim_set_playback_time(&animation, 1800);
    lv_anim_set_repeat_count(&animation, LV_ANIM_REPEAT_INFINITE);
    lv_anim_set_path_cb(&animation, lv_anim_path_ease_in_out);
    lv_anim_start(&animation);

    ui_versions = lv_label_create(ui_screen);
    lv_label_set_text_fmt(
        ui_versions,
        "ESP32_Display_Panel %d.%d.%d  |  LVGL %d.%d.%d",
        ESP_PANEL_VERSION_MAJOR, ESP_PANEL_VERSION_MINOR, ESP_PANEL_VERSION_PATCH,
        LVGL_VERSION_MAJOR, LVGL_VERSION_MINOR, LVGL_VERSION_PATCH
    );
    lv_obj_set_style_text_font(ui_versions, &lv_font_montserrat_16, 0);
    lv_obj_align(ui_versions, LV_ALIGN_BOTTOM_MID, 0, -30);

    apply_ui_palette(lv_color_hex(0x000000));
    lv_timer_create(change_background, 10000, nullptr);
}

void setup()
{
    debug_begin();
    pinMode(OLIMEX_USER_LED_PIN, OUTPUT);
    digitalWrite(OLIMEX_USER_LED_PIN, !OLIMEX_USER_LED_ACTIVE_LEVEL);
    delay(500);
    debug_printf("\n");
    debug_printf("Olimex ESP32-P4-DevKit MIPI-LCD2.8 Arduino LCD test\n");
    debug_printf("Mode %d: %s\n", OLIMEX_LCD_TEST_MODE,
                 (OLIMEX_LCD_TEST_MODE == TEST_MODE_DSI_PATTERN) ? "DSI hardware pattern" :
                 (OLIMEX_LCD_TEST_MODE == TEST_MODE_SOFTWARE_COLOR_BARS) ? "software color bars" :
                 "LVGL UI");
    debug_printf("Arduino USB CDC on boot: %d, USB mode: %d\n", ARDUINO_USB_CDC_ON_BOOT, ARDUINO_USB_MODE);
    debug_printf("LVGL color depth: %d, lv_color_t size: %u\n", LV_COLOR_DEPTH, (unsigned)sizeof(lv_color_t));
#if OLIMEX_MIPI_LCD_VERSION == 1
    debug_printf("V1 LCD: PCA9536 reset/backlight enabled; RGB565 LVGL converted to RGB888 display data\n");
#else
    debug_printf("V2 LCD: no PCA9536; RGB565 LVGL converted to RGB888 display data\n");
#endif
    debug_printf("PSRAM: total=%u free=%u; internal free=%u\n",
                 ESP.getPsramSize(), heap_caps_get_free_size(MALLOC_CAP_SPIRAM),
                 heap_caps_get_free_size(MALLOC_CAP_INTERNAL | MALLOC_CAP_8BIT));
    debug_printf("MIPI DSI config: lanes=%d, lane_rate=%d Mbps, dpi_clk=%d MHz, dpi_bits=%d\n",
                 ESP_PANEL_BOARD_LCD_MIPI_DSI_LANE_NUM,
                 ESP_PANEL_BOARD_LCD_MIPI_DSI_LANE_RATE_MBPS,
                 ESP_PANEL_BOARD_LCD_MIPI_DPI_CLK_MHZ,
                 ESP_PANEL_BOARD_LCD_MIPI_DPI_PIXEL_BITS);

    static_assert(LV_COLOR_DEPTH == 16, "This sketch expects LVGL RGB565");
    static_assert(sizeof(lv_color_t) == 2, "This sketch expects 16-bit lv_color_t");

    debug_printf("Initializing board\n");
    board = new Board();
    if ((board == nullptr) || !board->init()) {
        halt_with_message("Board init failed");
    }

#if LVGL_PORT_AVOID_TEARING_MODE
    auto lcd = board->getLCD();
    lcd->configFrameBufferNumber(LVGL_PORT_DISP_BUFFER_NUM);

#if ESP_PANEL_DRIVERS_BUS_ENABLE_RGB && CONFIG_IDF_TARGET_ESP32S3
    auto lcd_bus = lcd->getBus();
    if (lcd_bus->getBasicAttributes().type == ESP_PANEL_BUS_TYPE_RGB) {
        static_cast<BusRGB *>(lcd_bus)->configRGB_BounceBufferSize(lcd->getFrameWidth() * 10);
    }
#endif
#endif

    debug_printf("Beginning board\n");
    if (!board->begin()) {
        halt_with_message("Board begin failed");
    }

    auto lcd = board->getLCD();
    debug_printf("LCD frame: %dx%d, color bits: %d\n",
                 lcd->getFrameWidth(), lcd->getFrameHeight(), lcd->getFrameColorBits());

#if OLIMEX_LCD_TEST_MODE == TEST_MODE_DSI_PATTERN
    debug_printf("Showing MIPI DSI hardware color-bar pattern\n");
    if (!lcd->DSI_ColorBarPatternTest(LCD::DSI_ColorBarPattern::BAR_VERTICAL)) {
        halt_with_message("DSI pattern test failed");
    }
    debug_printf("DSI pattern is running; LVGL is not started in this mode\n");
    return;
#elif OLIMEX_LCD_TEST_MODE == TEST_MODE_SOFTWARE_COLOR_BARS
    debug_printf("Drawing software color bars through LCD::drawBitmap\n");
    if (!lcd->colorBarTest()) {
        halt_with_message("Software color-bar test failed");
    }
    debug_printf("Software color bars drawn; LVGL is not started in this mode\n");
    return;
#else
    debug_printf("Initializing LVGL\n");
    if (!lvgl_port_init(board->getLCD(), board->getTouch())) {
        halt_with_message("LVGL init failed");
    }

    debug_printf("Creating UI\n");
    lvgl_port_lock(-1);
    create_test_ui();
    lvgl_port_unlock();

    debug_printf("LCD initialized\n");
#endif
}

void loop()
{
    static uint32_t pattern_index = 0;
    static uint32_t last_led_toggle_ms = 0;
    static bool user_led_on = false;

    if ((millis() - last_led_toggle_ms) >= 500) {
        last_led_toggle_ms = millis();
        user_led_on = !user_led_on;
        digitalWrite(OLIMEX_USER_LED_PIN,
                     user_led_on ? OLIMEX_USER_LED_ACTIVE_LEVEL : !OLIMEX_USER_LED_ACTIVE_LEVEL);
    }

#if OLIMEX_DEBUG_SERIAL
    static uint32_t last_print_ms = 0;
    if ((millis() - last_print_ms) >= 2000) {
        last_print_ms = millis();
        debug_printf("alive, mode %d, uptime %lu ms\n", OLIMEX_LCD_TEST_MODE, (unsigned long)millis());
    }
#endif

#if OLIMEX_LCD_TEST_MODE == TEST_MODE_DSI_PATTERN
    if ((board != nullptr) && ((millis() / 3000) != pattern_index)) {
        pattern_index = millis() / 3000;
        auto lcd = board->getLCD();
        switch (pattern_index % 3) {
        case 0:
            lcd->DSI_ColorBarPatternTest(LCD::DSI_ColorBarPattern::BAR_VERTICAL);
            break;
        case 1:
            lcd->DSI_ColorBarPatternTest(LCD::DSI_ColorBarPattern::BAR_HORIZONTAL);
            break;
        default:
            lcd->DSI_ColorBarPatternTest(LCD::DSI_ColorBarPattern::BER_VERTICAL);
            break;
        }
    }
#endif

    delay(50);
}

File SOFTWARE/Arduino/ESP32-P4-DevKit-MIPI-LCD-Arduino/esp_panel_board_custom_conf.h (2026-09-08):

/*
 * SPDX-FileCopyrightText: 2023-2025 Espressif Systems (Shanghai) CO LTD
 *
 * SPDX-License-Identifier: Apache-2.0
 */
/**
 * @file   esp_panel_board_custom_conf.h
 * @brief  Configuration file for custom ESP development boards
 * @author
 * @link
 *
 * This file contains all the configurations needed for a custom board using ESP Panel.
 * Users can modify these configurations according to their hardware design.
 */

#pragma once

// *INDENT-OFF*

/**
 * @brief Flag to enable custom board configuration (0/1)
 *
 * Set to `1` to enable custom board configuration, `0` to disable
 */
#define ESP_PANEL_BOARD_DEFAULT_USE_CUSTOM  (1)

#if ESP_PANEL_BOARD_DEFAULT_USE_CUSTOM
// Display revision selector. Leave this at 2 for WLK2802MIPI-15P-V2.
// Set it to 1 for the original WLK2802MIPI-15P, which has a PCA9536 at 0x41.
#ifndef OLIMEX_MIPI_LCD_VERSION
#define OLIMEX_MIPI_LCD_VERSION (2)
#endif

#if (OLIMEX_MIPI_LCD_VERSION != 1) && (OLIMEX_MIPI_LCD_VERSION != 2)
#error "OLIMEX_MIPI_LCD_VERSION must be 1 or 2"
#endif

////////////////////////////////////////////////////////////////////////////////////////////////////////////////////////
///////////////////////// Please update the following macros to configure general parameters ///////////////////////////
////////////////////////////////////////////////////////////////////////////////////////////////////////////////////////
/**
 * @brief Board name (format: "Manufacturer:Model")
 */
#define ESP_PANEL_BOARD_NAME                "Olimex:ESP32-P4-DevKit"

/**
 * @brief Panel resolution configuration in pixels
 */
#define ESP_PANEL_BOARD_WIDTH               (480)   // Panel width (horizontal, in pixels)
#define ESP_PANEL_BOARD_HEIGHT              (640)   // Panel height (vertical, in pixels)

////////////////////////////////////////////////////////////////////////////////////////////////////////////////////////
//////////////////////////// Please update the following macros to configure the LCD panel /////////////////////////////
////////////////////////////////////////////////////////////////////////////////////////////////////////////////////////
/**
 * @brief LCD panel configuration flag (0/1)
 *
 * Set to `1` to enable LCD panel support, `0` to disable
 */
#define ESP_PANEL_BOARD_USE_LCD             (1)

#if ESP_PANEL_BOARD_USE_LCD
/**
 * @brief LCD controller selection
 *
 * Supported controllers:
 * - `AXS15231B`
 * - `EK9716B`, `EK79007`
 * - `GC9A01`, `GC9B71`, `GC9503`
 * - `HX8399`
 * - `ILI9341`, `ILI9881C`
 * - `JD9165`, `JD9365`
 * - `NV3022B`
 * - `SH8601`
 * - `SPD2010`
 * - `ST7262`, `ST7701`, `ST7703`, `ST7789`, `ST7796`, `ST77903`, `ST77916`, `ST77922`
 */
#define ESP_PANEL_BOARD_LCD_CONTROLLER      ST7701

/**
 * @brief LCD bus type selection
 *
 * Supported bus types:
 * - `ESP_PANEL_BUS_TYPE_SPI`
 * - `ESP_PANEL_BUS_TYPE_QSPI`
 * - `ESP_PANEL_BUS_TYPE_RGB` (ESP32-S3 only)
 * - `ESP_PANEL_BUS_TYPE_MIPI_DSI` (ESP32-P4 only)
 */
#define ESP_PANEL_BOARD_LCD_BUS_TYPE        (ESP_PANEL_BUS_TYPE_MIPI_DSI)

#if (ESP_PANEL_BOARD_LCD_BUS_TYPE == ESP_PANEL_BUS_TYPE_SPI) || \
    (ESP_PANEL_BOARD_LCD_BUS_TYPE == ESP_PANEL_BUS_TYPE_QSPI)
/**
 * If set to 1, the bus will skip to initialize the corresponding host. Users need to initialize the host in advance.
 *
 * For drivers which created by this library, even if they use the same host, the host will be initialized only once.
 * So it is not necessary to set the macro to `1`. For other drivers (like `Wire`), please set the macro to `1`
 * ensure that the host is initialized only once.
 */
#define ESP_PANEL_BOARD_LCD_BUS_SKIP_INIT_HOST      (0)     // 0/1. Typically set to 0
#endif
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

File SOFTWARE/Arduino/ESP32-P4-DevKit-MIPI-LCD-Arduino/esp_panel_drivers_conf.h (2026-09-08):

/*
 * Driver selection for Olimex ESP32-P4-DevKit + MIPI-LCD2.8-640x480.
 */

#pragma once

// *INDENT-OFF*

#define ESP_PANEL_DRIVERS_BUS_USE_ALL                       (0)
#if !ESP_PANEL_DRIVERS_BUS_USE_ALL
    #define ESP_PANEL_DRIVERS_BUS_USE_SPI                   (0)
    #define ESP_PANEL_DRIVERS_BUS_USE_QSPI                  (0)
    #define ESP_PANEL_DRIVERS_BUS_USE_RGB                   (0)
    #define ESP_PANEL_DRIVERS_BUS_USE_I2C                   (1)
    #define ESP_PANEL_DRIVERS_BUS_USE_MIPI_DSI              (1)
#endif
#define ESP_PANEL_DRIVERS_BUS_COMPILE_UNUSED_DRIVERS        (0)

#define ESP_PANEL_DRIVERS_LCD_USE_ALL                       (0)
#if !ESP_PANEL_DRIVERS_LCD_USE_ALL
    #define ESP_PANEL_DRIVERS_LCD_USE_AXS15231B             (0)
    #define ESP_PANEL_DRIVERS_LCD_USE_EK9716B               (0)
    #define ESP_PANEL_DRIVERS_LCD_USE_EK79007               (0)
    #define ESP_PANEL_DRIVERS_LCD_USE_GC9A01                (0)
    #define ESP_PANEL_DRIVERS_LCD_USE_GC9B71                (0)
    #define ESP_PANEL_DRIVERS_LCD_USE_GC9503                (0)
    #define ESP_PANEL_DRIVERS_LCD_USE_HX8399                (0)
    #define ESP_PANEL_DRIVERS_LCD_USE_ILI9341               (0)
    #define ESP_PANEL_DRIVERS_LCD_USE_ILI9881C              (0)
    #define ESP_PANEL_DRIVERS_LCD_USE_JD9165                (0)
    #define ESP_PANEL_DRIVERS_LCD_USE_JD9365                (0)
    #define ESP_PANEL_DRIVERS_LCD_USE_NV3022B               (0)
    #define ESP_PANEL_DRIVERS_LCD_USE_SH8601                (0)
    #define ESP_PANEL_DRIVERS_LCD_USE_SPD2010               (0)
    #define ESP_PANEL_DRIVERS_LCD_USE_ST7262                (0)
    #define ESP_PANEL_DRIVERS_LCD_USE_ST7701                (1)
    #define ESP_PANEL_DRIVERS_LCD_USE_ST7703                (0)
    #define ESP_PANEL_DRIVERS_LCD_USE_ST7789                (0)
    #define ESP_PANEL_DRIVERS_LCD_USE_ST7796                (0)
    #define ESP_PANEL_DRIVERS_LCD_USE_ST77903               (0)
    #define ESP_PANEL_DRIVERS_LCD_USE_ST77916               (0)
    #define ESP_PANEL_DRIVERS_LCD_USE_ST77922               (0)
#endif
#define ESP_PANEL_DRIVERS_LCD_COMPILE_UNUSED_DRIVERS        (0)

#define ESP_PANEL_DRIVERS_TOUCH_MAX_POINTS                  (10)
#define ESP_PANEL_DRIVERS_TOUCH_MAX_BUTTONS                 (5)
#define ESP_PANEL_DRIVERS_TOUCH_USE_ALL                     (0)
#if !ESP_PANEL_DRIVERS_TOUCH_USE_ALL
    #define ESP_PANEL_DRIVERS_TOUCH_USE_AXS15231B           (0)
    #define ESP_PANEL_DRIVERS_TOUCH_USE_CHSC6540            (0)
    #define ESP_PANEL_DRIVERS_TOUCH_USE_CST816S             (0)
    #define ESP_PANEL_DRIVERS_TOUCH_USE_CST820              (0)
    #define ESP_PANEL_DRIVERS_TOUCH_USE_FT5x06              (0)
    #define ESP_PANEL_DRIVERS_TOUCH_USE_GSL3680             (0)
    #define ESP_PANEL_DRIVERS_TOUCH_USE_GT911               (0)
    #define ESP_PANEL_DRIVERS_TOUCH_USE_GT1151              (0)
    #define ESP_PANEL_DRIVERS_TOUCH_USE_SPD2010             (0)
    #define ESP_PANEL_DRIVERS_TOUCH_USE_ST1633              (0)
    #define ESP_PANEL_DRIVERS_TOUCH_USE_ST7123              (0)
    #define ESP_PANEL_DRIVERS_TOUCH_USE_STMPE610            (0)
    #define ESP_PANEL_DRIVERS_TOUCH_USE_TT21100             (0)
    #define ESP_PANEL_DRIVERS_TOUCH_USE_XPT2046             (0)
#endif
#define ESP_PANEL_DRIVERS_TOUCH_COMPILE_UNUSED_DRIVERS      (0)

#define ESP_PANEL_DRIVERS_EXPANDER_USE_ALL                  (0)
#if !ESP_PANEL_DRIVERS_EXPANDER_USE_ALL
    #define ESP_PANEL_DRIVERS_EXPANDER_USE_CH422G           (0)
    #define ESP_PANEL_DRIVERS_EXPANDER_USE_HT8574           (0)
    #define ESP_PANEL_DRIVERS_EXPANDER_USE_TCA95XX_8BIT     (1)
    #define ESP_PANEL_DRIVERS_EXPANDER_USE_TCA95XX_16BIT    (0)
#endif

#define ESP_PANEL_DRIVERS_BACKLIGHT_USE_ALL                 (0)
#if !ESP_PANEL_DRIVERS_BACKLIGHT_USE_ALL
    #define ESP_PANEL_DRIVERS_BACKLIGHT_USE_SWITCH_GPIO     (0)
    #define ESP_PANEL_DRIVERS_BACKLIGHT_USE_SWITCH_EXPANDER (1)
    #define ESP_PANEL_DRIVERS_BACKLIGHT_USE_PWM_LEDC        (0)
    #define ESP_PANEL_DRIVERS_BACKLIGHT_USE_CUSTOM          (0)
#endif
#define ESP_PANEL_DRIVERS_BACKLIGHT_COMPILE_UNUSED_DRIVERS  (0)

#define ESP_PANEL_DRIVERS_CONF_FILE_VERSION_MAJOR 1
#define ESP_PANEL_DRIVERS_CONF_FILE_VERSION_MINOR 2
#define ESP_PANEL_DRIVERS_CONF_FILE_VERSION_PATCH 0

// *INDENT-ON*

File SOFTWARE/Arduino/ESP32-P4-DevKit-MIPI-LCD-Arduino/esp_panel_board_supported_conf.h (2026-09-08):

/*
 * Keep the ESP32_Display_Panel built-in board selector disabled.
 * This sketch uses esp_panel_board_custom_conf.h for the Olimex wiring.
 */

#pragma once

#define ESP_PANEL_BOARD_DEFAULT_USE_SUPPORTED       (0)

#if ESP_PANEL_BOARD_DEFAULT_USE_SUPPORTED
#define ESP_PANEL_BOARD_SUPPORTED_FILE_VERSION_MAJOR 1
#define ESP_PANEL_BOARD_SUPPORTED_FILE_VERSION_MINOR 3
#define ESP_PANEL_BOARD_SUPPORTED_FILE_VERSION_PATCH 0
#endif

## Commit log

2024-12-13 initial upload
    [ESP32-P4-DevKit_Rev_B-B_Cu.gbr, ESP32-P4-DevKit_Rev_B-B_Mask.gbr, ESP32-P4-DevKit_Rev_B-B_Paste.gbr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]
2024-12-16 add demo examples
    [partitions_example.csv]
2025-04-14 Update
    Hardware revision C
    [ESP32-P4-DevKit_Rev_C-B_Cu.gbr, ESP32-P4-DevKit_Rev_C-B_Mask.gbr, ESP32-P4-DevKit_Rev_C-B_Paste.gbr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]
2025-06-09 Update
    New demo examples
    [partitions.csv]
2025-12-03 Update
    HDMI demo with MIPI-HDMI adapter
    [partitions.csv]
2026-03-18 Update
    Added ESP32-P4-DevKit-Lipo examples for Arduino IDE
2026-06-26 Update
    Added documents for revisions D and D1
    [ESP32-P4-DevKit_Rev_D-B_Cu.gbr, ESP32-P4-DevKit_Rev_D-B_Mask.gbr, ESP32-P4-DevKit_Rev_D-B_Paste.gbr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]
2026-09-09 Update
    Added LED pulse and improved README

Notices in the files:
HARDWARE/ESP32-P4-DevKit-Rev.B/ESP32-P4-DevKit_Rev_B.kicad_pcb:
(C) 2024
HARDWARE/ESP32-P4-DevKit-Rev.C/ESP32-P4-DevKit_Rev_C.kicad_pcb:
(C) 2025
